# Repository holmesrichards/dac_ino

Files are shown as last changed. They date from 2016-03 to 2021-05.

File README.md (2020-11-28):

# dac/ino

This is a pair of boards and corresponding library which provide CV and gate I/O for an Arduino Nano. It is derived from [shaduzlabs/synapse](https://github.com/shaduzlabs/synapse), and there are obvious similarities to [ArdCore](http://20objects.com/ardcore/), but there are significant differences with both. 

There are two boards, dac/ino and dac/ino lite.

Differences between these and Synapse are:

- Board design with space for Arduino Nano, instead of as Uno style shield
- No on-board jacks — pads for Molex or pin connectors (or direct soldering) instead
- Simplification by eliminating software-controlled range selection
- Number of inputs and outputs is different
- dac/ino lite is battery powered and has 0–5 V output range, also uses Arduino Vcc as voltage reference

## Features
### dac/ino has
- 4 x control voltage inputs, 0 to 5V
- 2 x control voltage outputs, individually configurable as 0 to 5 V, 0 to 10 V, or -5 to 5 V via jumpers, with 12 bits of resolution
- 4 x gate inputs (with interrupt)
- 2 x gate outputs
- Additional inputs/outputs (direct connections to Arduino): 4 analog, 2 digital
- All above inputs/outputs connect via Molex connectors or solder pads, or via pin headers for daughterboards
- Voltage reference chip
- 1 x eurorack power connector (10 pin)

### dac/ino lite has
- 2 x control voltage outputs, 0 to 5 V, with 12 bits of resolution
- 1 x gate output
- Additional inputs/outputs (direct connections to Arduino): 4 analog, 2 digital
- All above inputs/outputs connect via Molex connectors or solder pads
- 6–12 V battery or unipolar power supply

## Compatible Arduinos
The PCB layout is for an Arduino Nano (5V).

## Dependencies
- [DirectIO](https://github.com/mmarchetti/DirectIO), for fast digital pin access

## Respository
- KiCad format schematics and PCB layouts, and Arduino library and example sketches, may be found at [https://github.com/holmesrichards/dac_ino](https://github.com/holmesrichards/dac_ino).

- [Build notes](docs/Build_notes.md)
- [dac/ino schematic](docs/dac_ino.pdf) (A bit confusing because the repetitive parts of the circuit are handled with KiCad heirarchical pages, so you have lots of pages with only a few components on each.)

- [dac/ino PCB layout](docs/dac_ino_pcb.pdf)

- [dac/ino BOM](docs/dac_ino_bom.md)

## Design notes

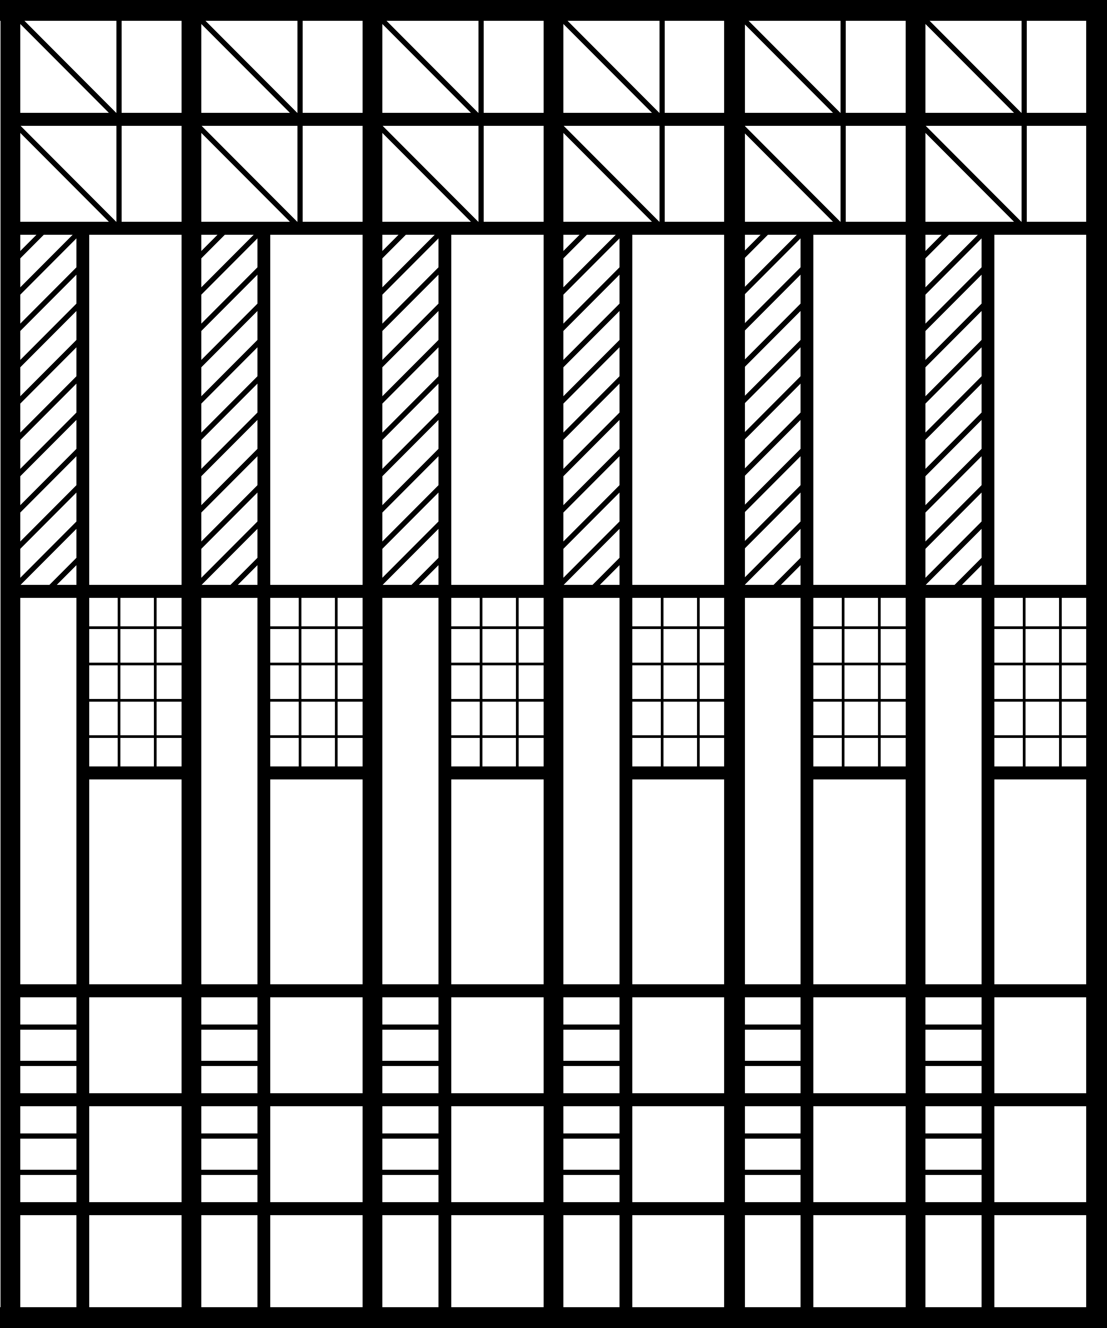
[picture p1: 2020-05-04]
hardware/dac_ino/deco2_dac_ino.png

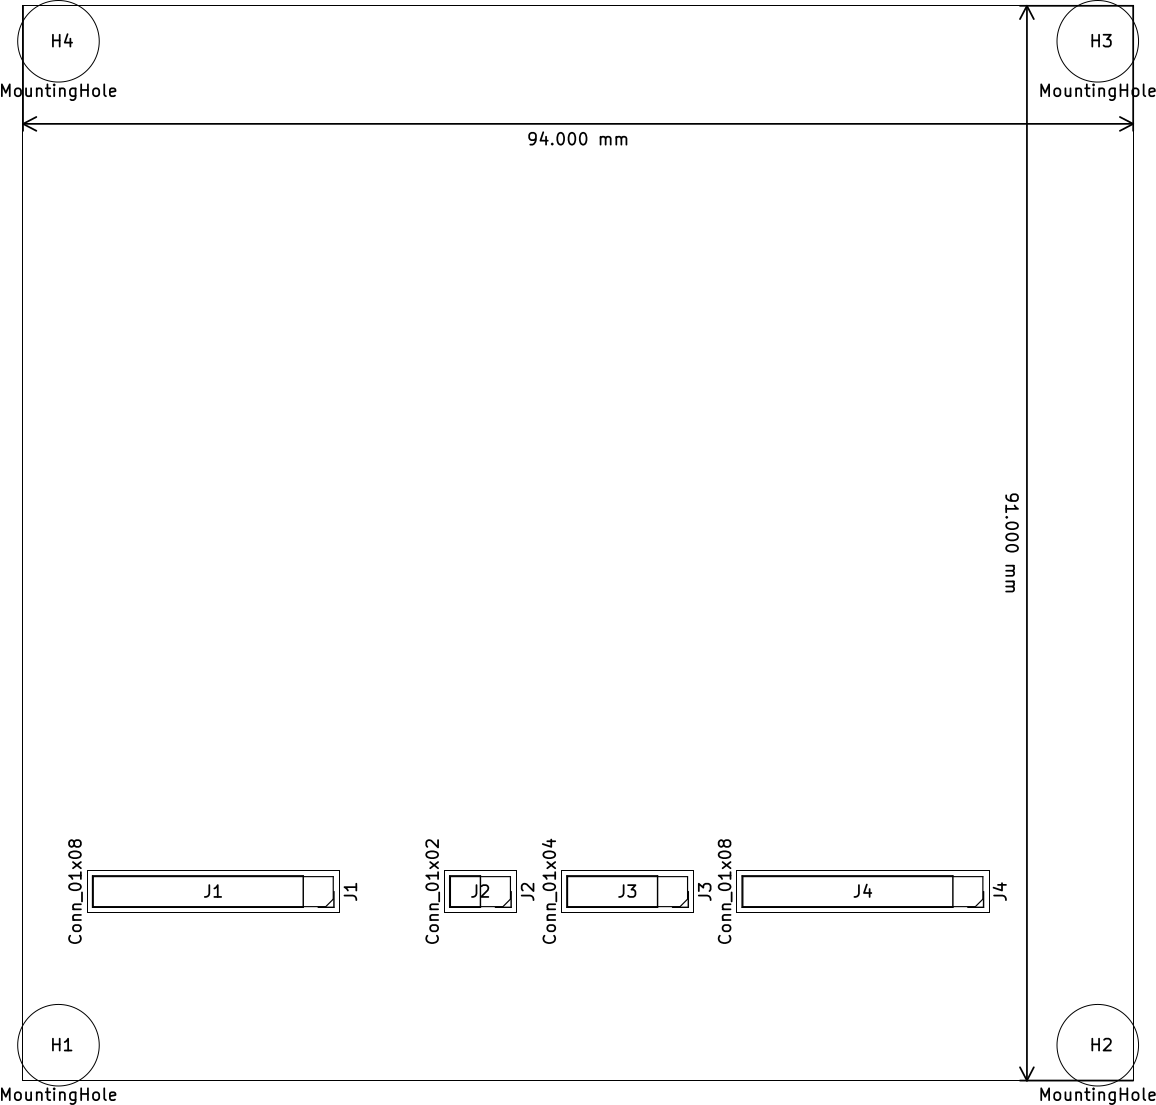
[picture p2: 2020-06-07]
hardware/daughterboard/daughterboard.png

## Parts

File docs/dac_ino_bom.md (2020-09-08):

# dac_ino BOM

Tue 08 Sep 2020 07:13:33 PM EDT

Generated from schematic by Eeschema 5.1.6-c6e7f7d~87~ubuntu20.04.1

**Component Count:** 83

| Value | Qty | Part | Description | Vendor |
| ----- | --- | ---- | --- | --- |
| A1 | 1 | Arduino_Nano_v3.x 5V | Arduino Nano v3.x |  |
| C1, C7, C8 | 3 | 10uF | Polarized capacitor |  |
| C2, C3, C4 | 3 | 0.1uF | Unpolarized capacitor |  |
| C5, C6 | 2 | 47pF | Unpolarized capacitor |  |
| D1, D2, D3, D4, D5, D6, D7, D8, D9, D10 | 10 | 1N5817 | 20V 1A Schottky Barrier Rectifier Diode, DO-41 |  |
| H1, H2, H3, H4 | 4 | MountingHole | Mounting Hole without connection |  |
| J1, J2 | 2 | Conn_01x03_Male | Generic connector, single row, 01x03, script generated (kicad-library-utils/schlib/autogen/connector/) |  |
| J3, J4 | 2 | Molex 2 pin CV OUT | Generic connector, single row, 01x02, script generated (kicad-library-utils/schlib/autogen/connector/) |  |
| J5, J6 | 2 | Molex 2 pin GATE OUT | Generic connector, single row, 01x02, script generated (kicad-library-utils/schlib/autogen/connector/) |  |
| J7, J14 | 2 | Conn_01x01_Units | Generic connector, single row, 01x01, script generated (kicad-library-utils/schlib/autogen/connector/) |  |
| J8 | 1 | Molex 2 pin VCC  | Generic connector, single row, 01x02, script generated (kicad-library-utils/schlib/autogen/connector/) |  |
| J9 | 1 | EURO_PWR_2x5 |  |  |
| J10 | 1 | Conn_01x04 | Generic connector, single row, 01x04, script generated (kicad-library-utils/schlib/autogen/connector/) |  |
| J11 | 1 | Conn_01x02 | Generic connector, single row, 01x02, script generated (kicad-library-utils/schlib/autogen/connector/) |  |
| J12, J13, J19, J20 | 4 | Molex 2 pin GATE IN | Generic connector, single row, 01x02, script generated (kicad-library-utils/schlib/autogen/connector/) |  |
| J15, J16, J17, J18 | 4 | Molex 2 pin CV IN | Generic connector, single row, 01x02, script generated (kicad-library-utils/schlib/autogen/connector/) |  |
| J21 | 1 | Conn_01x06 | Generic connector, single row, 01x08, script generated (kicad-library-utils/schlib/autogen/connector/) |  |
| Q1, Q2, Q3, Q4, Q5, Q6 | 6 | 2N3904 | 0.2A Ic, 40V Vce, Small Signal NPN Transistor, TO-92 |  |
| R1, R14, R17, R20, R27, R30 | 6 | 10k | Resistor |  |
| R2, R3 | 2 | 91k | Resistor |  |
| R4, R5 | 2 | 20k | Trim-potentiometer |  |
| R6, R7, R15, R18, R25, R28 | 6 | 100k | Resistor |  |
| R8, R9, R10, R11, R12, R13, R21, R22, R23, R24 | 10 | 1k | Resistor |  |
| R16, R19, R26, R29 | 4 | 1M | Resistor |  |
| U1 | 1 | MCP4922 | 2-Channel 12-Bit D/A Converters with SPI Interface |  |
| U2 | 1 | TL072 | Dual Low-Noise JFET-Input Operational Amplifiers, DIP-8/SOIC-8 |  |
| U3 | 1 | REF02CP+ | High Precision, 5V Reference, DIP-8, SO-8 |  |

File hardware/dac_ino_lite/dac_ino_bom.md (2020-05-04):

# dac_ino BOM

Mon 04 May 2020 10:25:07 AM EDT

Generated from schematic by Eeschema 5.1.5-52549c5~84~ubuntu18.04.1

**Component Count:** 23

| Value | Qty | Part | Description | Vendor |
| ----- | --- | ---- | --- | --- |
| A1 | 1 | Arduino_Nano_v3.x 5V | Arduino Nano v3.x |  |
| C1, C4 | 2 | 10uF | Polarized capacitor |  |
| C2 | 1 | 0.1uF | Unpolarized capacitor |  |
| H1, H2, H3, H4 | 4 | MountingHole | Mounting Hole without connection |  |
| J1 | 1 | CV OUT A | Generic connector, single row, 01x02, script generated (kicad-library-utils/schlib/autogen/connector/) |  |
| J2 | 1 | CV OUT B | Generic connector, single row, 01x02, script generated (kicad-library-utils/schlib/autogen/connector/) |  |
| J5 | 1 | GATE OUT A | Generic connector, single row, 01x02, script generated (kicad-library-utils/schlib/autogen/connector/) |  |
| J6, J7 | 2 | Conn_01x04 | Generic connector, single row, 01x04, script generated (kicad-library-utils/schlib/autogen/connector/) |  |
| J8 | 1 | VCC | Generic connector, single row, 01x02, script generated (kicad-library-utils/schlib/autogen/connector/) |  |
| J9 | 1 | Vin | Generic connector, single row, 01x02, script generated (kicad-library-utils/schlib/autogen/connector/) |  |
| Q1 | 1 | 2N3904 | 0.2A Ic, 40V Vce, Small Signal NPN Transistor, TO-92 |  |
| R1, R8 | 2 | 10k | Resistor |  |
| R2, R3, R6, R7 | 4 | 1k | Resistor |  |
| U1 | 1 | MCP4922 | 2-Channel 12-Bit D/A Converters with SPI Interface |  |

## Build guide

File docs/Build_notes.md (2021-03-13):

# dac/ino build notes

## General build notes
The main thing to say about building this board is that it is very modular. Most components are associated with one particular input or output and if that input/output is not needed, those components can be omitted.

For example (for the full dac/ino board, similar ideas apply to dac/ino lite):

If you do not need Gate In D you can omit J13, Q4, R18, R19, R20

If you do not need CV In D you can omit D9, D10, J18, R24

If you do not need Gate Out B you can omit J6, Q2, R12, R13

If you do not need CV Out B you can omit C6, J2, J4, R3, R5, R7, R9 (use a wire jumper in place of C6)

Note that R14 is placed near the CV inputs but is not associated with them and should always be installed.

## Full dac/ino

### Silkscreen error
In version 1.3, the silkscreened reference numbers and values for R28 and R29 are reversed. R29 (1M) should be between R28 (100k) and R30 (10k). Fixed in version 1.31. Corrected version looks like this:

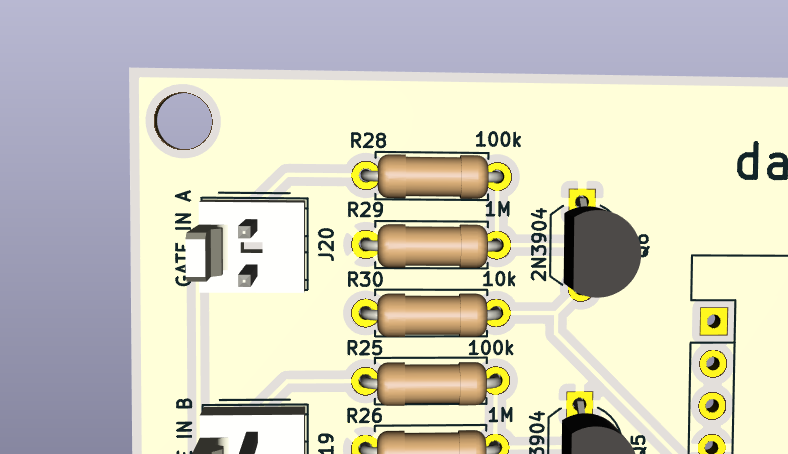
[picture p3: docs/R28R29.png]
R28 and R29 correct positions
 
### dac/ino build notes

The two 1x8 pin headers J7 and J14 duplicate the 2-pin Molex connectors; either or both can be installed and either can be used to connect to the Gate and CV inputs and outputs, and to access VCC and ground. 8-pin Molex connector J21, or in headers J10 and J11, provide access to two additional digital pins and four additional analog pins; these can be used for e.g. panel switches and pots where input protection and conditioning is not needed. Of course you can also omit any of the Molex connectors or pin headers and solder wires directly between the panel and board.

Pin headers J1 and J2 are for output CV range selection. Use a jumper to connect the middle pin to the pin toward the power header edge of the board to get 0–10 V, or the middle pin to the pin toward the CV In edge of the board to get ±5 V; omit the jumper to get 0–5 V. Use trimmers R4 and R5 to adjust the output gain.

Orient the Arduino Nano with the USB connector pointing toward the Analog Output logo.

## dac/ino lite

Provide power to this board by connecting a 6 to 12 V DC source to J9. The "+" on the silkscreen indicates which pin receives voltage, the other is ground.

There are no Gate or CV inputs provided; there are solder pads for direct connection to four digital and four analog pins.

R2 and R3 are output current limiting resistors.

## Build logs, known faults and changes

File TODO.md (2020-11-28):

# dac/ino ideas for future improvements

* ±5 V output relies on VCC for bias. Really should rely on voltage reference instead.

* Gate inputs are not protected against negative inputs. (Reverse voltage rating for 2N3904 is 6 V.) Add 1N4148 between base and ground.

* Limitation to 0–5 V inputs is unsatisfactory. A CV input that can optionally divide by 2 and optionally offset by 2.5 V would allow converting 0–10 V or ±5 V to the 0–5 V range. This would add several components including a quad op amp. Perhaps use e.g. MCP6004 powered with VCC and ground, obviating need for Schottkys for Arduino protection.

* Board is inconveniently wide already and we're talking about adding components! Consider: 
    * Converting design to 2-layer sandwich
    * Surface mount design
    * Switching to DAC with internal voltage reference (2.5 V or 5 V would be good but I see none in through hole package, just MCP4822 with 2.048 V)

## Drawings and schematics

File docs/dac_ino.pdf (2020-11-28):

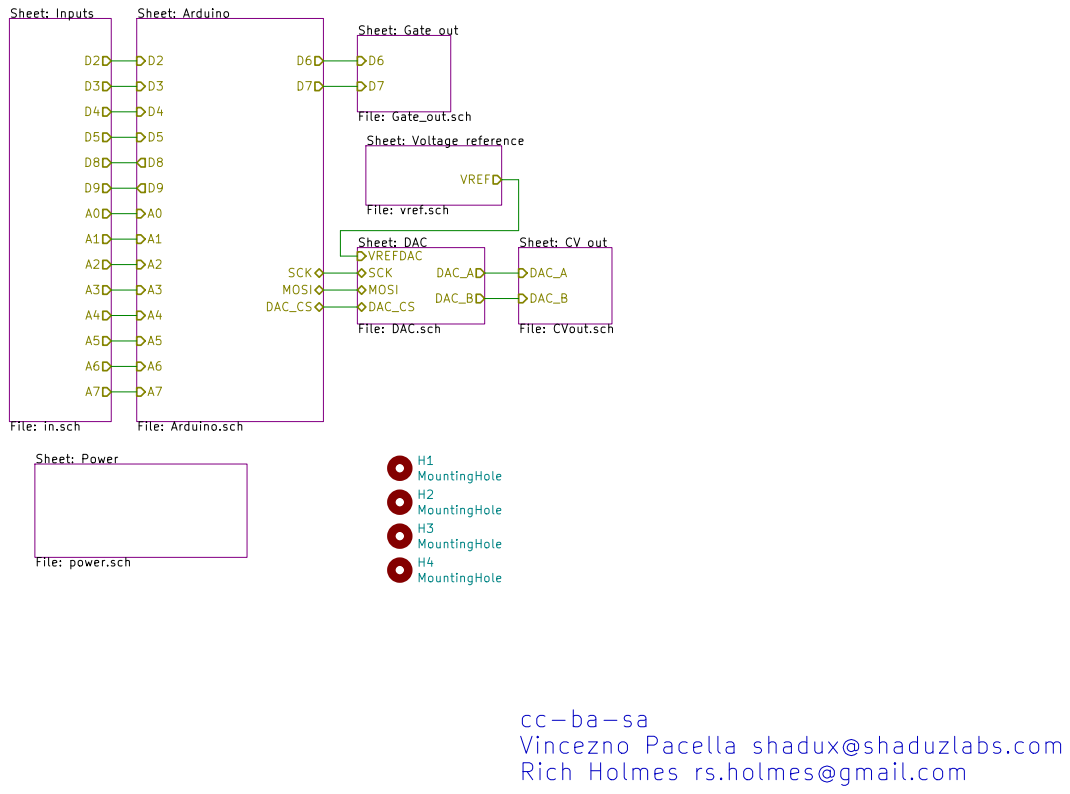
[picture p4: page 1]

Sheet: CV out File: CVout.sch DAC_A DAC_B

Vincezno Pacella shadux@shaduzlabs.com
Rich Holmes rs.holmes@gmail.com

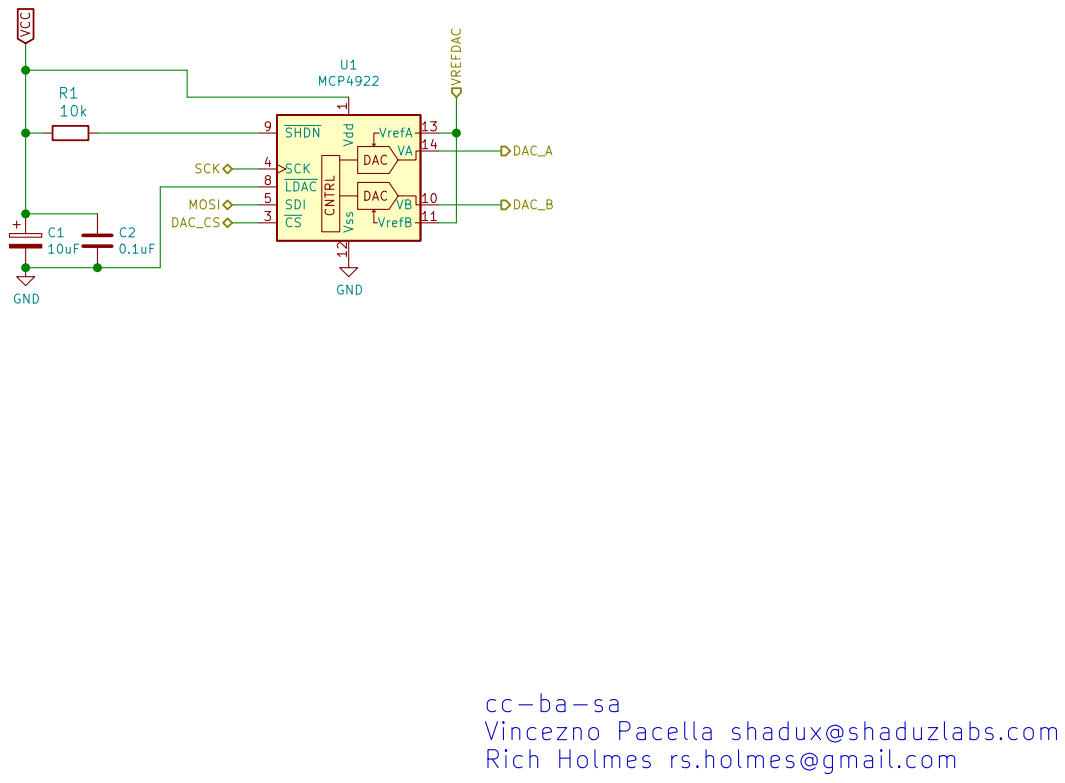
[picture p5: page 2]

1 VB 10 VrefB 11 Vss 12 VrefA 13 VA 14 CS 3 SCK 4 SDI 5

Vincezno Pacella shadux@shaduzlabs.com
Rich Holmes rs.holmes@gmail.com

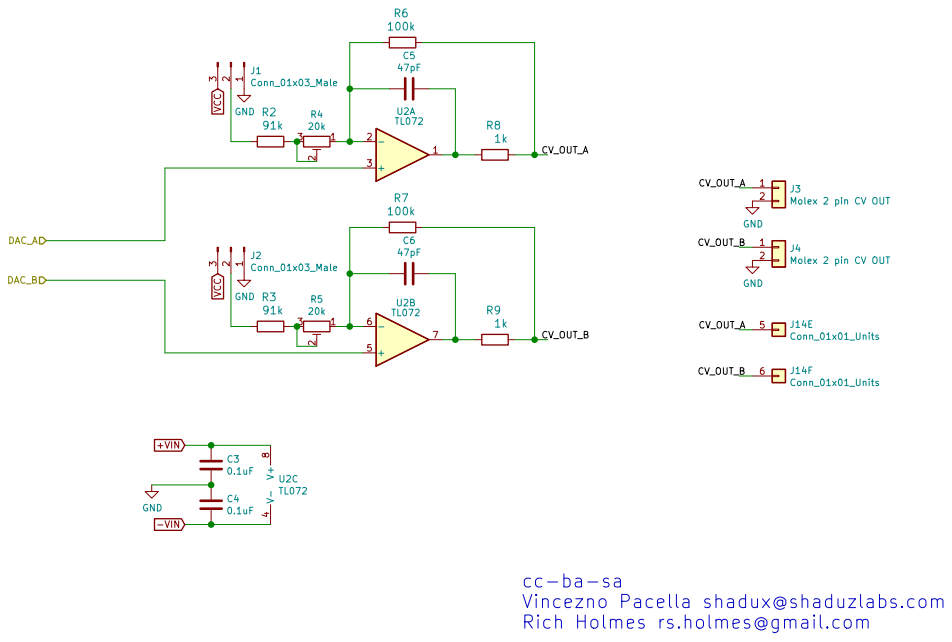
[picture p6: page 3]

Vincezno Pacella shadux@shaduzlabs.com
Rich Holmes rs.holmes@gmail.com

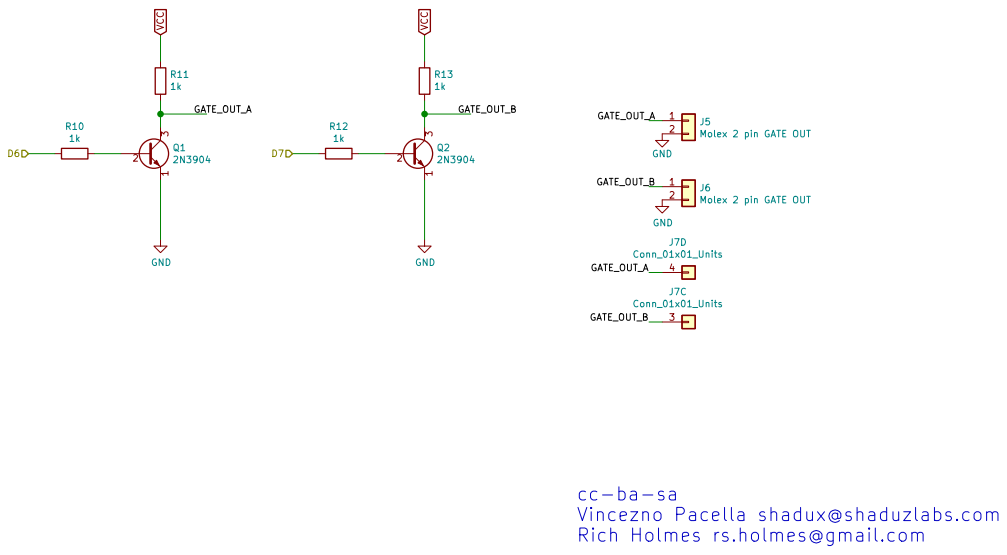
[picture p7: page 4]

Vincezno Pacella shadux@shaduzlabs.com
Rich Holmes rs.holmes@gmail.com

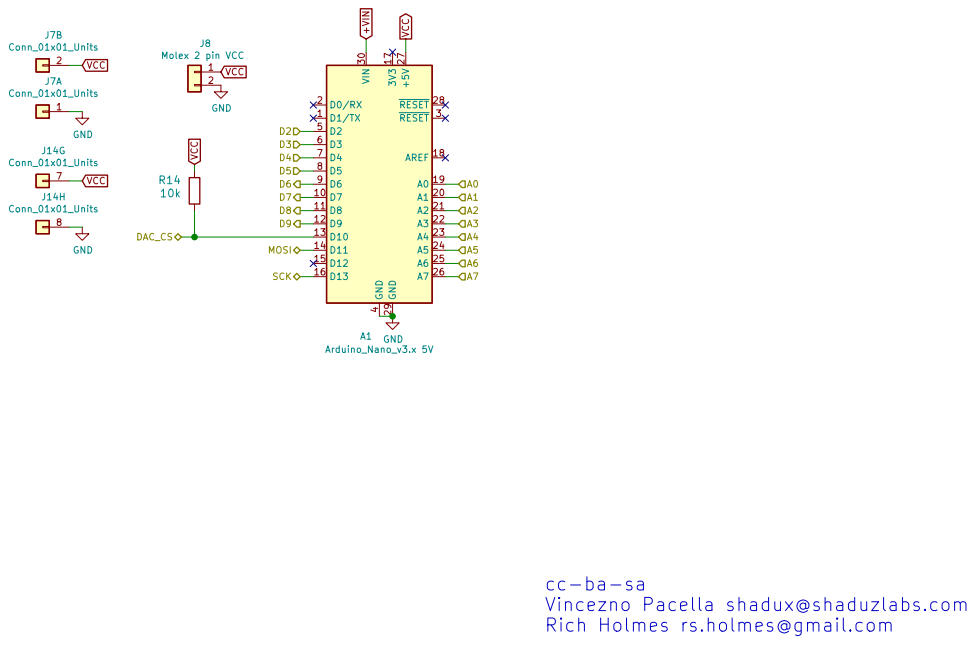
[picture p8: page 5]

J8 Molex 2 pin VCC GND

Vincezno Pacella shadux@shaduzlabs.com
Rich Holmes rs.holmes@gmail.com

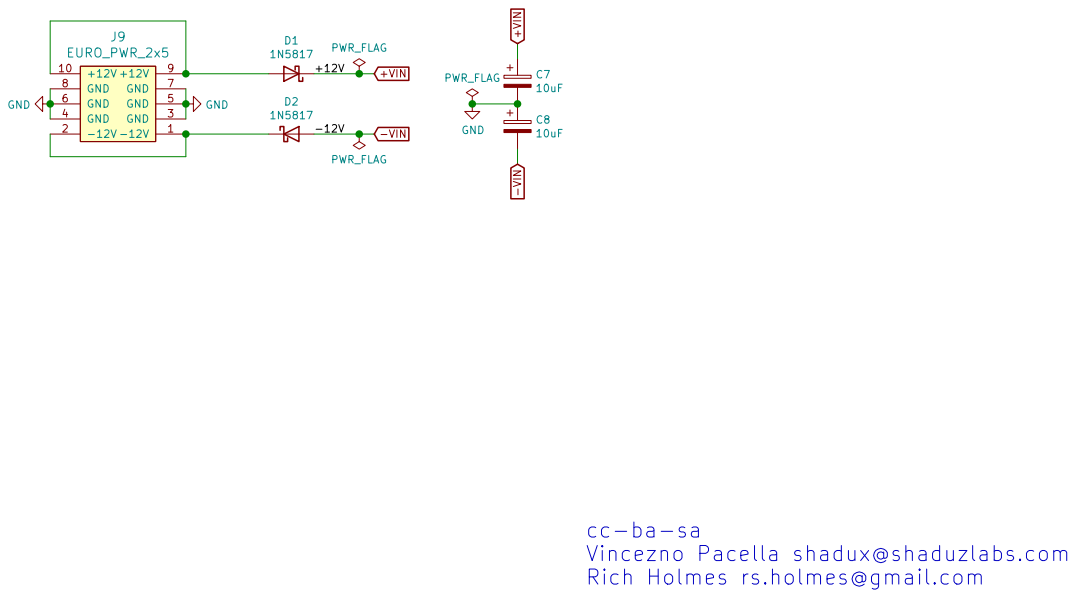
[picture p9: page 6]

Vincezno Pacella shadux@shaduzlabs.com
Rich Holmes rs.holmes@gmail.com

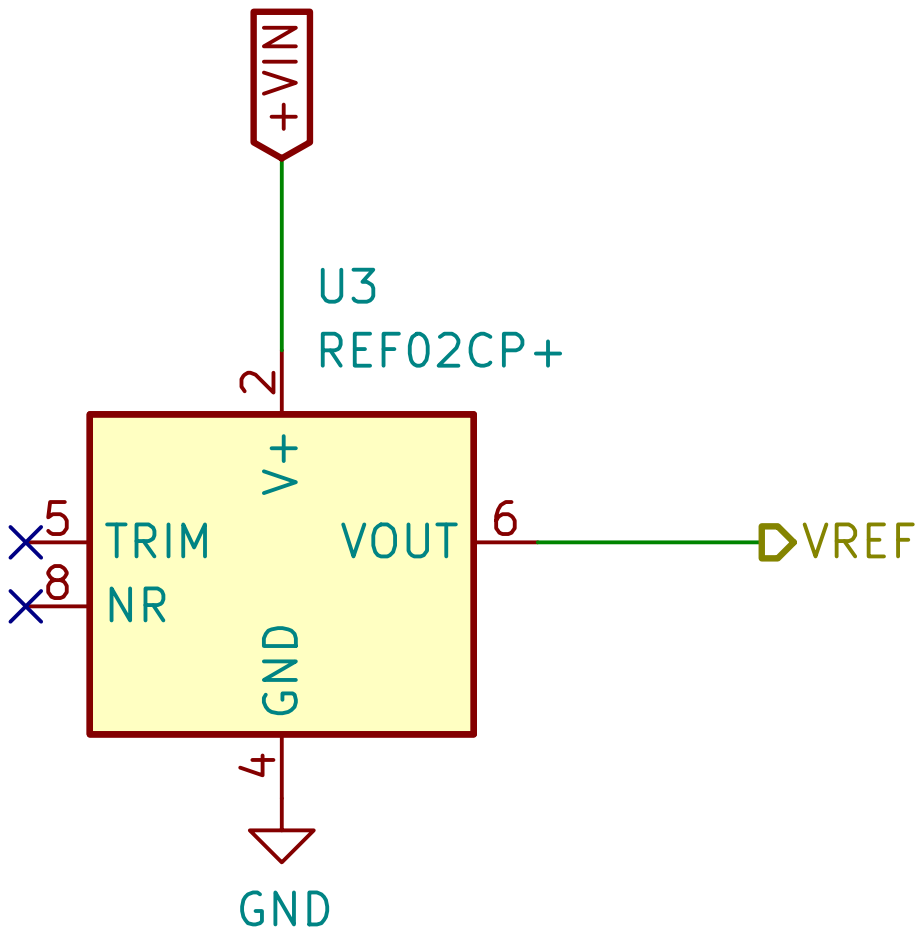
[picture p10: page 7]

4 TRIM 5 VOUT 6 NR 8 U3REF02CP+ GND

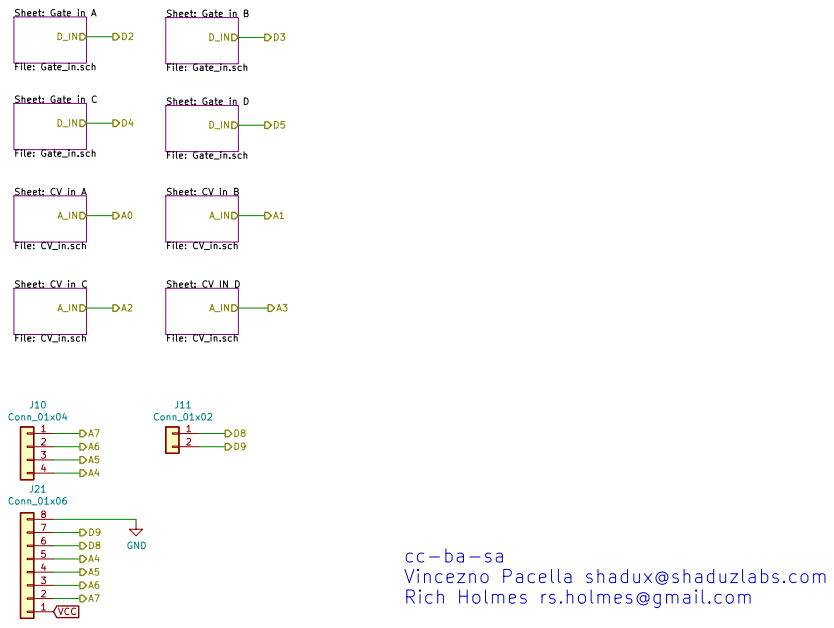
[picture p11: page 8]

Vincezno Pacella shadux@shaduzlabs.com
Rich Holmes rs.holmes@gmail.com

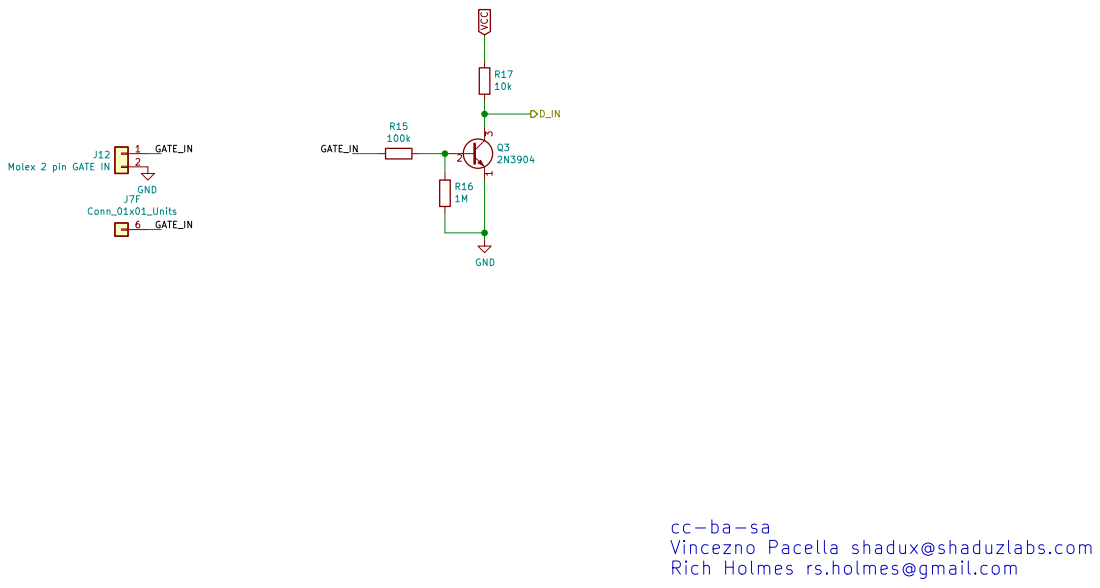
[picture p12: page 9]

J12 Molex 2 pin GATE IN

Vincezno Pacella shadux@shaduzlabs.com
Rich Holmes rs.holmes@gmail.com

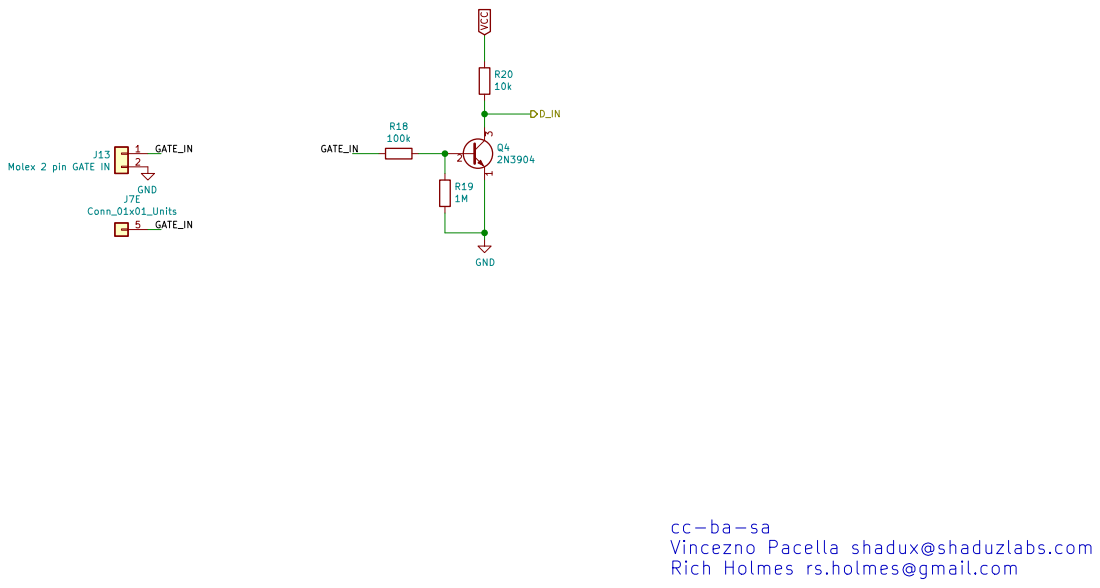
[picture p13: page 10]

J13 Molex 2 pin GATE IN

Vincezno Pacella shadux@shaduzlabs.com
Rich Holmes rs.holmes@gmail.com

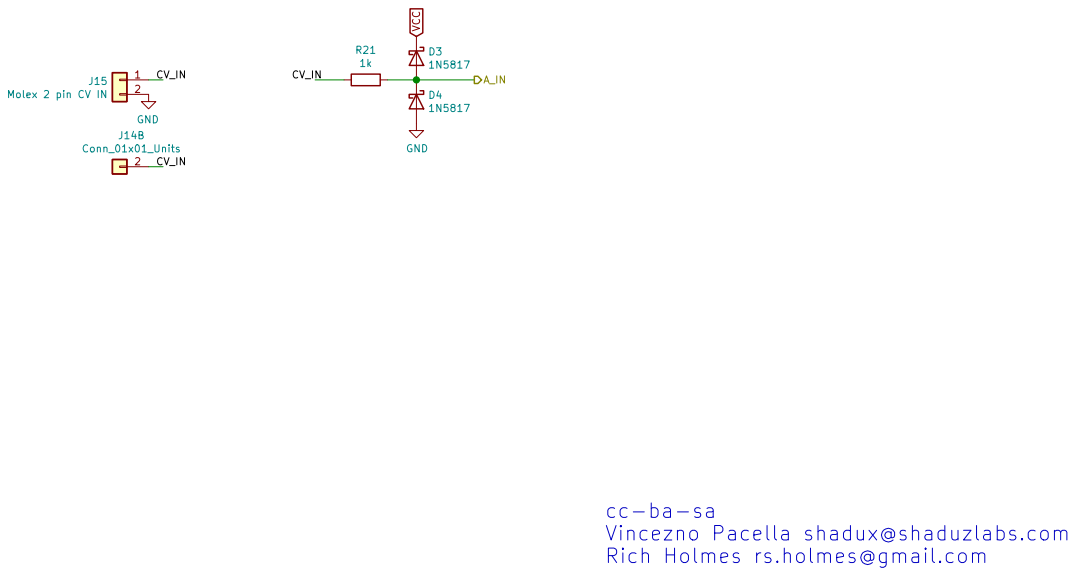
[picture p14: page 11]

J15 Molex 2 pin CV IN

Vincezno Pacella shadux@shaduzlabs.com
Rich Holmes rs.holmes@gmail.com

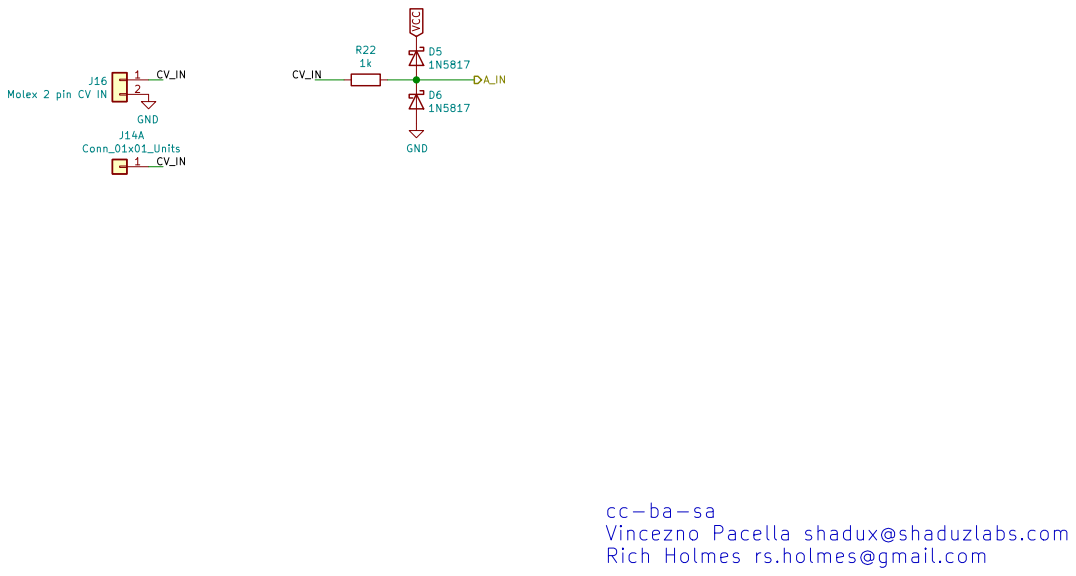
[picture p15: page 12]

J16 Molex 2 pin CV IN

Vincezno Pacella shadux@shaduzlabs.com
Rich Holmes rs.holmes@gmail.com


J17 Molex 2 pin CV IN

Vincezno Pacella shadux@shaduzlabs.com
Rich Holmes rs.holmes@gmail.com


J18 Molex 2 pin CV IN

Vincezno Pacella shadux@shaduzlabs.com
Rich Holmes rs.holmes@gmail.com


J19 Molex 2 pin GATE IN

Vincezno Pacella shadux@shaduzlabs.com
Rich Holmes rs.holmes@gmail.com


J20 Molex 2 pin GATE IN

Vincezno Pacella shadux@shaduzlabs.com
Rich Holmes rs.holmes@gmail.com





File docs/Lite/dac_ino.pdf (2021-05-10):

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

based on Synapse by Vincenzo Pacella shadux@shaduzlabs.com
File: dac_ino.sch Sheet: / Rich Holmes / Analog Output

Id: 1/1 Title: dac/ino lite

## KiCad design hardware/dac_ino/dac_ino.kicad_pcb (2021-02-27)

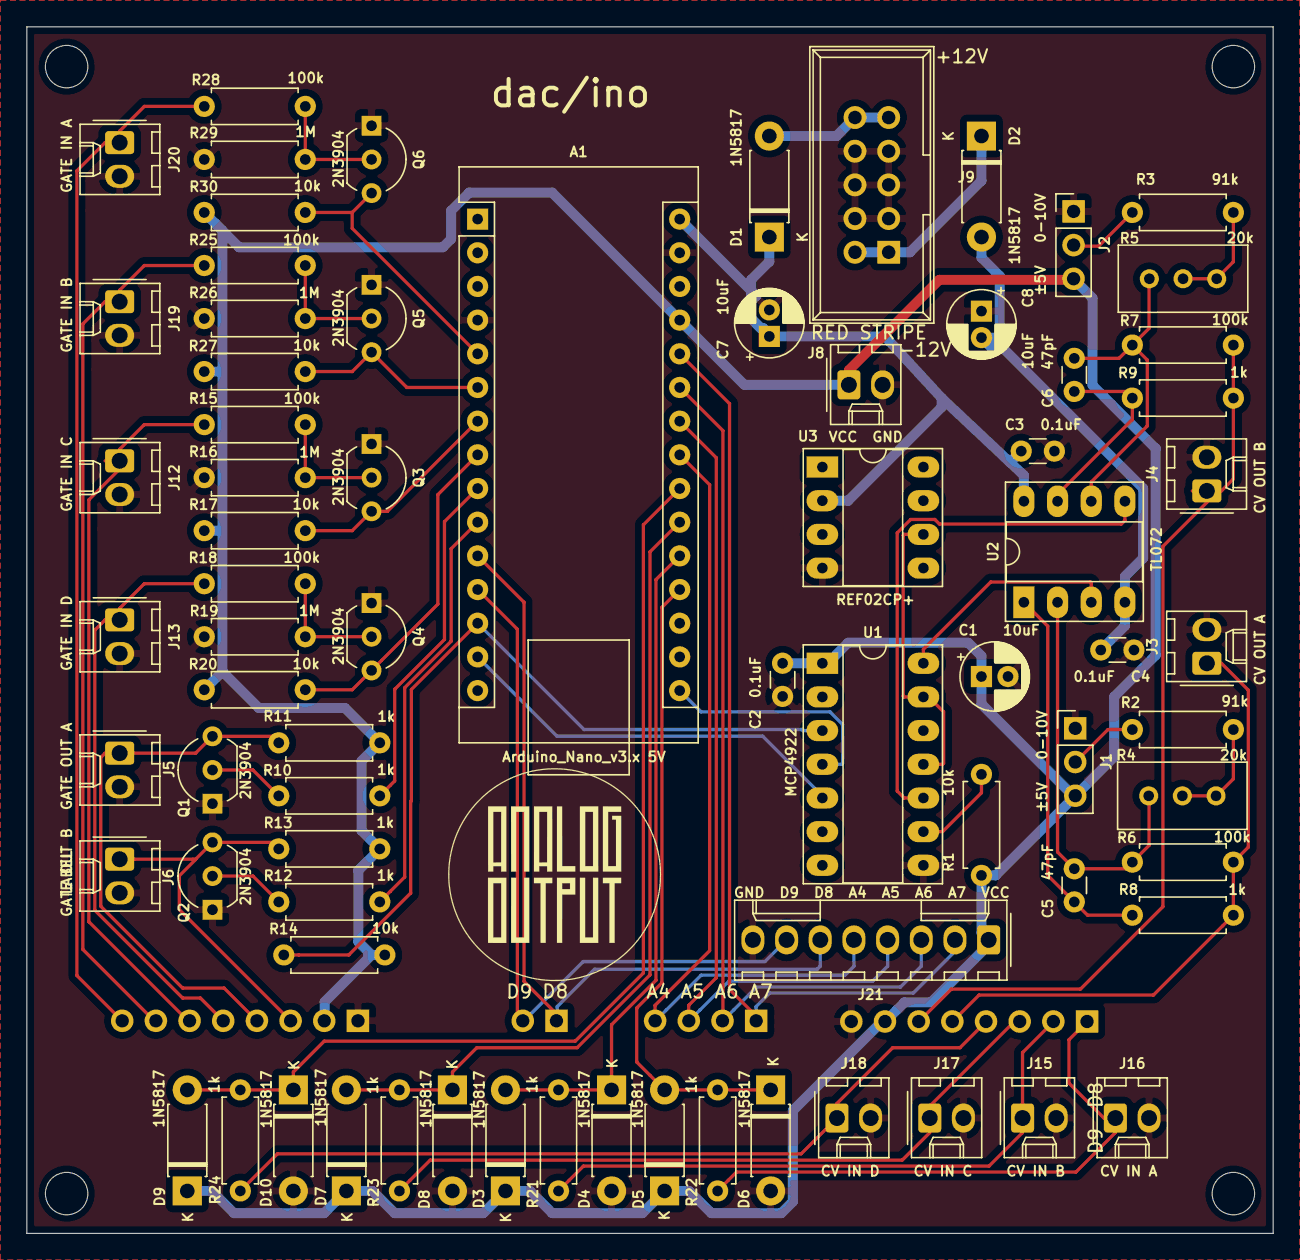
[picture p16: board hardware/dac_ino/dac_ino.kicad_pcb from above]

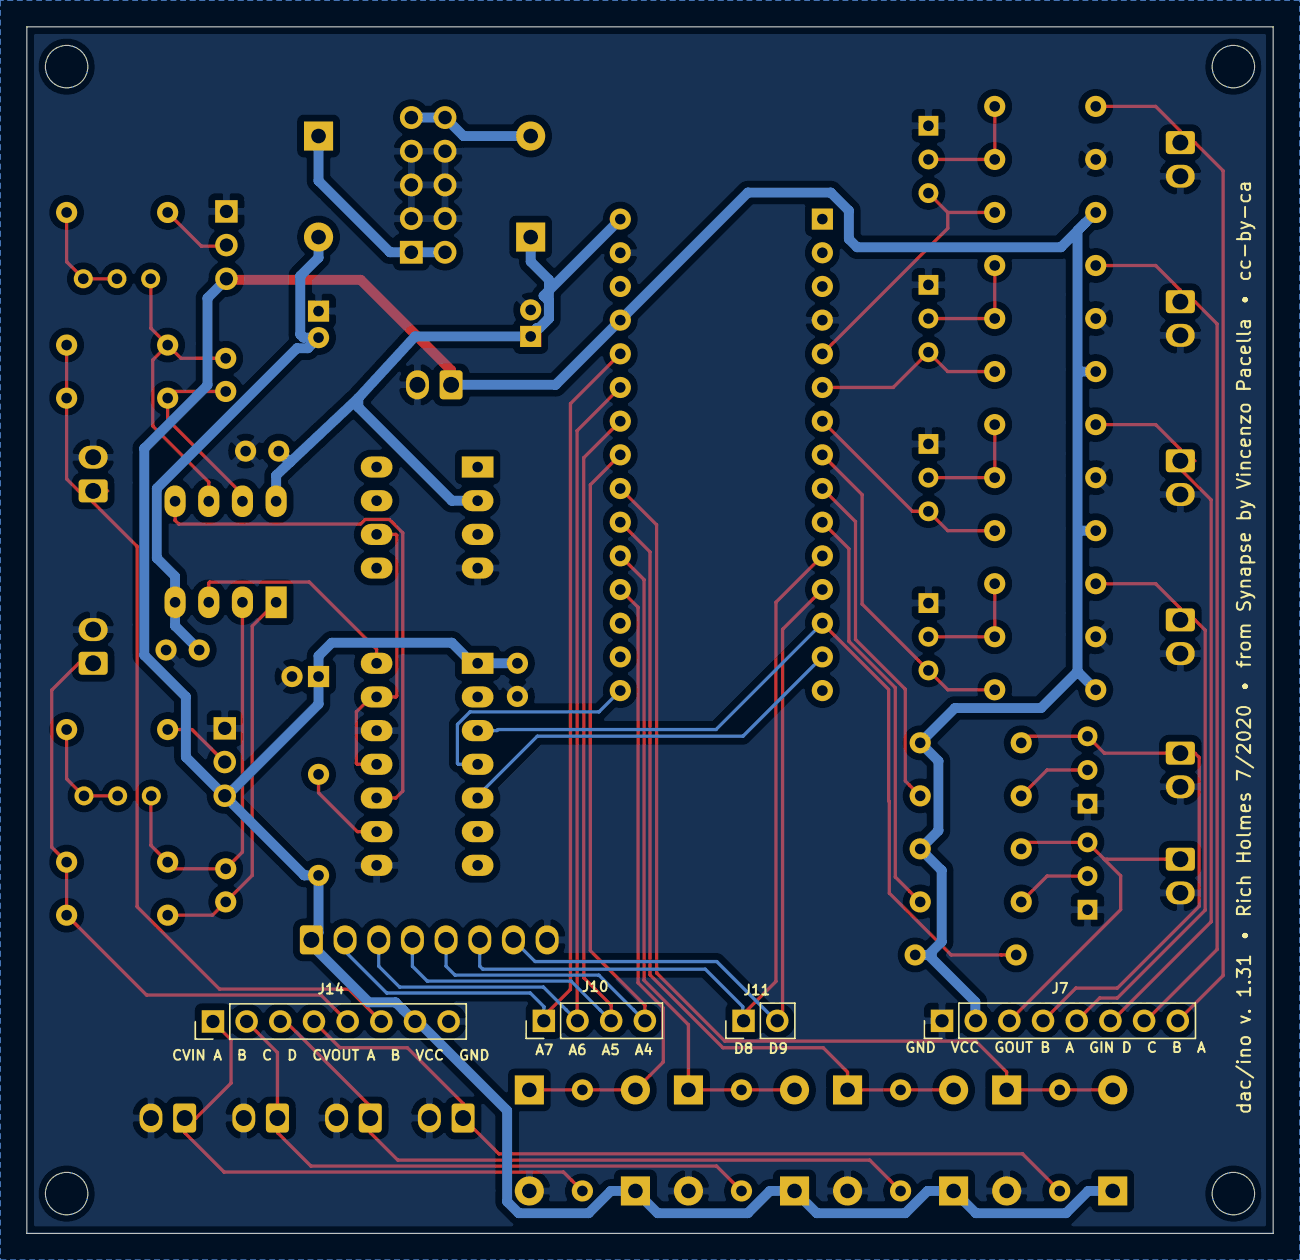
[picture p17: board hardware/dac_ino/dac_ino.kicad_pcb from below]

Board: 2 copper layers, 94.0 x 91.0 mm, 83 parts (4 on the bottom side), 55 nets.

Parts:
A1: Arduino_Nano_v3.x 5V; Arduino_Nano
C1, C7, C8: 10uF; CP_Radial_D5.0mm_P2.00mm
C2, C3, C4: 0.1uF; C_Disc_D3.0mm_W1.6mm_P2.50mm
C5, C6: 47pF; C_Disc_D3.0mm_W1.6mm_P2.50mm
D1, D2, D3, D4, D5, D6, D7, D8, D9, D10: 1N5817; D_DO-41_SOD81_P7.62mm_Horizontal
H1, H2, H3, H4: MountingHole; MountingHole_3.2mm_M3
J1, J2: Conn_01x03_Male; PinHeader_1x03_P2.54mm_Vertical
J3, J4: Molex 2 pin CV OUT; Molex_KK-254_AE-6410-02A_1x02_P2.54mm_Vertical
J5, J6: Molex 2 pin GATE OUT; Molex_KK-254_AE-6410-02A_1x02_P2.54mm_Vertical
J7, J14: Conn_01x01_Units; PinHeader_1x08_P2.54mm_Vertical
J8: Molex 2 pin VCC; Molex_KK-254_AE-6410-02A_1x02_P2.54mm_Vertical
J9: EURO_PWR_2x5; Power_Header
J10: Conn_01x04; PinHeader_1x04_P2.54mm_Vertical
J11: Conn_01x02; PinHeader_1x02_P2.54mm_Vertical
J12, J13, J19, J20: Molex 2 pin GATE IN; Molex_KK-254_AE-6410-02A_1x02_P2.54mm_Vertical
J15, J16, J17, J18: Molex 2 pin CV IN; Molex_KK-254_AE-6410-02A_1x02_P2.54mm_Vertical
J21: Conn_01x06; Molex_KK-254_AE-6410-08A_1x08_P2.54mm_Vertical
Q1, Q2, Q3, Q4, Q5, Q6: 2N3904; TO-92_Inline_Wide
R1, R14, R17, R20, R27, R30: 10k; R_Axial_DIN0207_L6.3mm_D2.5mm_P7.62mm_Horizontal
R2, R3: 91k; R_Axial_DIN0207_L6.3mm_D2.5mm_P7.62mm_Horizontal
R4, R5: 20k; Potentiometer_Bourns_3296W_Vertical
R6, R7, R15, R18, R25, R28: 100k; R_Axial_DIN0207_L6.3mm_D2.5mm_P7.62mm_Horizontal
R8, R9, R10, R11, R12, R13, R21, R22, R23, R24: 1k; R_Axial_DIN0207_L6.3mm_D2.5mm_P7.62mm_Horizontal
R16, R19, R26, R29: 1M; R_Axial_DIN0207_L6.3mm_D2.5mm_P7.62mm_Horizontal
U1: MCP4922; DIP-14_W7.62mm_Socket_LongPads
U2: TL072; DIP-8_W7.62mm_Socket_LongPads
U3: REF02CP+; DIP-8_W7.62mm_Socket_LongPads

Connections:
+VIN: A1.30, C3.1, C7.1, D1.1, U2.8, U3.2
-VIN: C4.2, C8.2, D2.2, U2.4
/Arduino/A0: A1.19, D5.2, D6.1, R22.1
/Arduino/A1: A1.20, D3.2, D4.1, R21.1
/Arduino/A2: A1.21, D7.2, D8.1, R23.1
/Arduino/A3: A1.22, D9.2, D10.1, R24.1
/Arduino/A4: A1.23, J10.4, J21.5
/Arduino/A5: A1.24, J10.3, J21.4
/Arduino/A6: A1.25, J10.2, J21.3
/Arduino/A7: A1.26, J10.1, J21.2
/Arduino/D2: A1.5, Q6.3, R30.1
/Arduino/D3: A1.6, Q5.3, R27.1
/Arduino/D4: A1.7, Q3.3, R17.1
/Arduino/D5: A1.8, Q4.3, R20.1
/Arduino/D6: A1.9, R10.2
/Arduino/D7: A1.10, R12.2
/Arduino/D8: A1.11, J11.1, J21.6
/Arduino/D9: A1.12, J11.2, J21.7
/Arduino/DAC_CS: A1.13, R14.2, U1.3
/Arduino/MOSI: A1.14, U1.5
/Arduino/SCK: A1.16, U1.4
/CV out/CV_OUT_A: J3.1, J14.5, R6.2, R8.2
/CV out/CV_OUT_B: J4.1, J14.6, R7.2, R9.2
/CV out/DAC_A: U1.14, U2.3
/CV out/DAC_B: U1.10, U2.5
/Gate out/GATE_OUT_A: J5.1, J7.4, Q1.3, R11.1
/Gate out/GATE_OUT_B: J6.1, J7.3, Q2.3, R13.1
/Inputs/CV IN D/CV_IN: J14.4, J18.1, R24.2
/Inputs/CV in A/CV_IN: J14.1, J16.1, R22.2
/Inputs/CV in B/CV_IN: J14.2, J15.1, R21.2
/Inputs/CV in C/CV_IN: J14.3, J17.1, R23.2
/Inputs/Gate in A/GATE_IN: J7.8, J20.1, R28.2
/Inputs/Gate in B/GATE_IN: J7.7, J19.1, R25.2
/Inputs/Gate in C/GATE_IN: J7.6, J12.1, R15.2
/Inputs/Gate in D/GATE_IN: J7.5, J13.1, R18.2
/Voltage reference/VREF: U1.11, U1.13, U3.6
GND: A1.4, A1.29, C1.2, C2.2, C3.2, C4.1, C7.2, C8.1, D4.2, D6.2, D8.2, D10.2, J1.1, J2.1, J3.2, J4.2, J5.2, J6.2, J7.1, J8.2, J9.3, J9.4, J9.5, J9.6, J9.7, J9.8, J12.2, J13.2, J14.8, J15.2, J16.2, J17.2, J18.2, J19.2, J20.2, J21.8, Q1.1, Q2.1, Q3.1, Q4.1, Q5.1, Q6.1, R16.1, R19.1, R26.1, R29.1, U1.8, U1.12, U3.4
unnamed: C5.1, R8.1, U2.1
unnamed: C5.2, R4.1, R6.1, U2.2
unnamed: C6.1, R9.1, U2.7
unnamed: C6.2, R5.1, R7.1, U2.6
unnamed: D1.2, J9.9, J9.10
unnamed: D2.1, J9.1, J9.2
unnamed: J1.2, R2.1
unnamed: J2.2, R3.1
unnamed: Q1.2, R10.1
unnamed: Q2.2, R12.1
unnamed: Q3.2, R15.1, R16.2
unnamed: Q4.2, R18.1, R19.2
unnamed: Q5.2, R25.1, R26.2
unnamed: Q6.2, R28.1, R29.2
unnamed: R1.2, U1.9
unnamed: R2.2, R4.2, R4.3
unnamed: R3.2, R5.2, R5.3
VCC: A1.27, C1.1, C2.1, D3.1, D5.1, D7.1, D9.1, J1.3, J2.3, J7.2, J8.1, J14.7, J21.1, R1.1, R11.2, R13.2, R14.1, R17.2, R20.2, R27.2, R30.2, U1.1

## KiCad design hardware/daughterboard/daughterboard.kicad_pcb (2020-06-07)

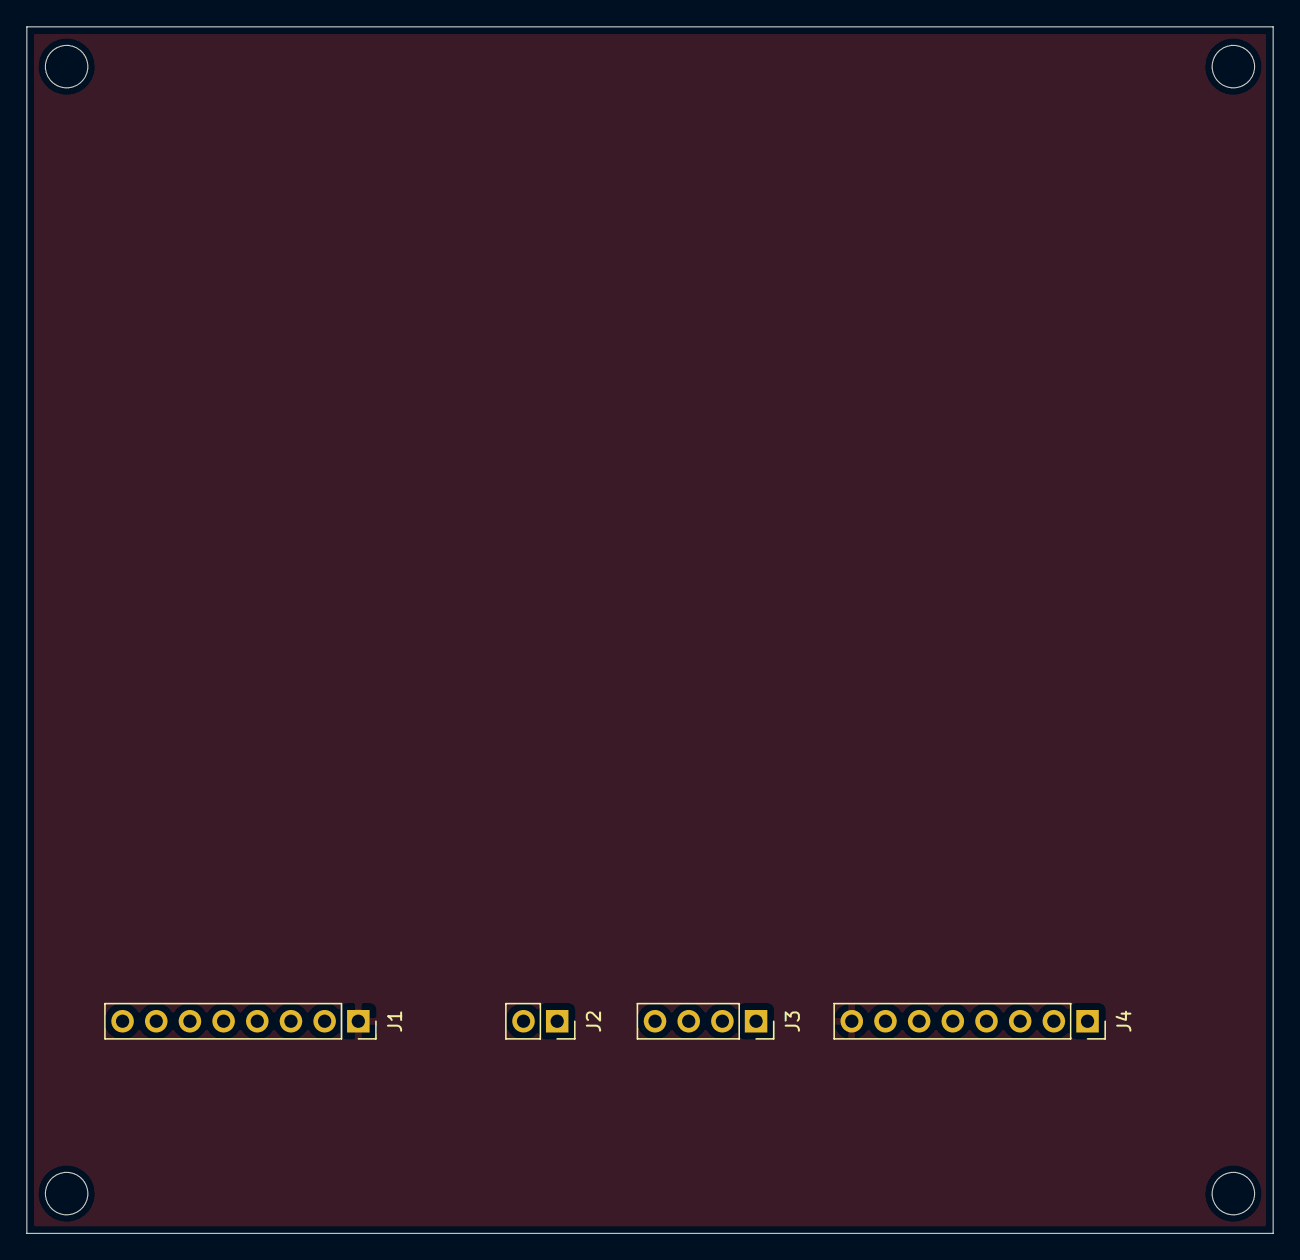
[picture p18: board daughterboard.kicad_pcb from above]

Board: 2 copper layers, 94.0 x 91.0 mm, 8 parts (0 on the bottom side), 2 nets, no tracks yet.

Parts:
H1, H2, H3, H4: MountingHole; MountingHole_3.2mm_M3
J1, J4: Conn_01x08; PinSocket_1x08_P2.54mm_Vertical
J2: Conn_01x02; PinSocket_1x02_P2.54mm_Vertical
J3: Conn_01x04; PinSocket_1x04_P2.54mm_Vertical

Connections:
GND: J1.1, J4.8
VCC: J1.2, J4.7

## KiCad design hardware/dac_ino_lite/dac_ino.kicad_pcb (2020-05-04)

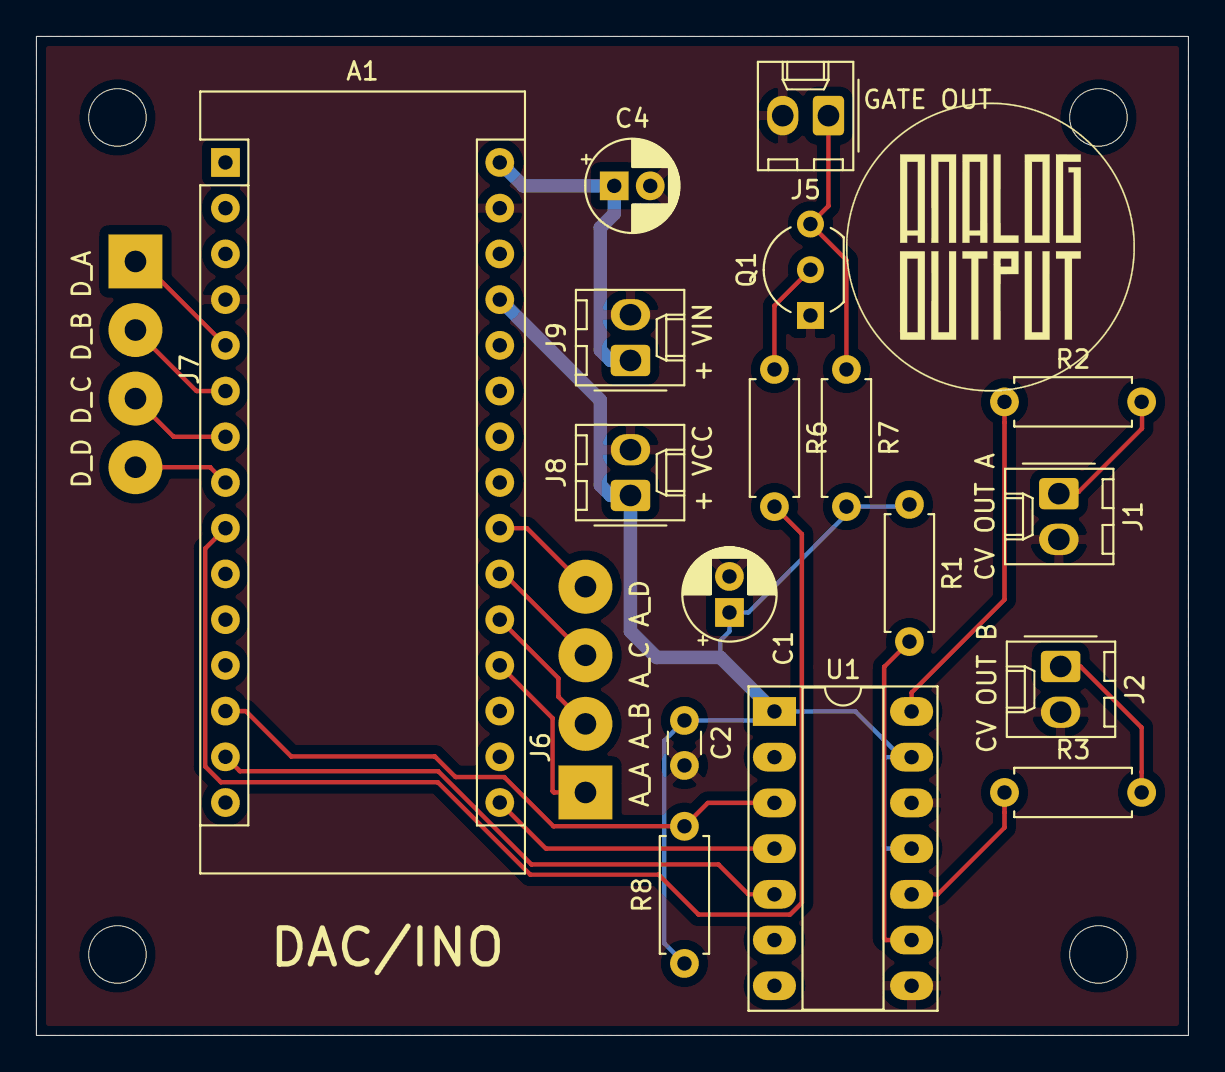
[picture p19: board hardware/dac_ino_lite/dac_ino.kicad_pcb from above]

Board: 2 copper layers, 64.0 x 55.5 mm, 23 parts (0 on the bottom side), 22 nets.

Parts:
A1: Arduino_Nano_v3.x 5V; Arduino_Nano
C1, C4: 10uF; CP_Radial_D5.0mm_P2.00mm
C2: 0.1uF; C_Disc_D3.0mm_W1.6mm_P2.50mm
H1, H2, H3, H4: MountingHole; MountingHole_3.2mm_M3
J1: CV OUT A; Molex_KK-254_AE-6410-02A_1x02_P2.54mm_Vertical
J2: CV OUT B; Molex_KK-254_AE-6410-02A_1x02_P2.54mm_Vertical
J5: GATE OUT A; Molex_KK-254_AE-6410-02A_1x02_P2.54mm_Vertical
J6, J7: Conn_01x04; SolderWirePad_1x04_P3.81mm_Drill1.2mm
J8: VCC; Molex_KK-254_AE-6410-02A_1x02_P2.54mm_Vertical
J9: Vin; Molex_KK-254_AE-6410-02A_1x02_P2.54mm_Vertical
Q1: 2N3904; TO-92_Inline_Wide
R1, R8: 10K; R_Axial_DIN0207_L6.3mm_D2.5mm_P7.62mm_Horizontal
R2, R3: 1K; R_Axial_DIN0207_L6.3mm_D2.5mm_P7.62mm_Horizontal
R6, R7: 1k; R_Axial_DIN0207_L6.3mm_D2.5mm_P7.62mm_Horizontal
U1: MCP4922; DIP-14_W7.62mm_Socket_LongPads

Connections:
+VIN: A1.30, C4.1, J9.1
/Arduino/A_IN_A: A1.19, J6.1
/Arduino/A_IN_B: A1.20, J6.2
/Arduino/A_IN_C: A1.21, J6.3
/Arduino/A_IN_D: A1.22, J6.4
/Arduino/DAC_CS: A1.13, R8.2, U1.3
/Arduino/D_IN_A: A1.5, J7.1
/Arduino/D_IN_B: A1.6, J7.2
/Arduino/D_IN_C: A1.7, J7.3
/Arduino/D_IN_D: A1.8, J7.4
/Arduino/D_OUT_A: A1.9, R6.2
/Arduino/MOSI: A1.14, U1.5
/Arduino/SCK: A1.16, U1.4
/DAC/CV_OUT_A: J1.1, R2.2
/DAC/CV_OUT_B: J2.1, R3.2
/Gate out/GATE_OUT: J5.1, Q1.3, R7.1
GND: A1.4, A1.29, C1.2, C2.2, C4.2, J1.2, J2.2, J5.2, J8.2, J9.2, Q1.1, U1.8, U1.12
unnamed: Q1.2, R6.1
unnamed: R1.2, U1.9
unnamed: R2.1, U1.14
unnamed: R3.1, U1.10
VCC: A1.27, C1.1, C2.1, J8.1, R1.1, R7.2, R8.1, U1.1, U1.11, U1.13

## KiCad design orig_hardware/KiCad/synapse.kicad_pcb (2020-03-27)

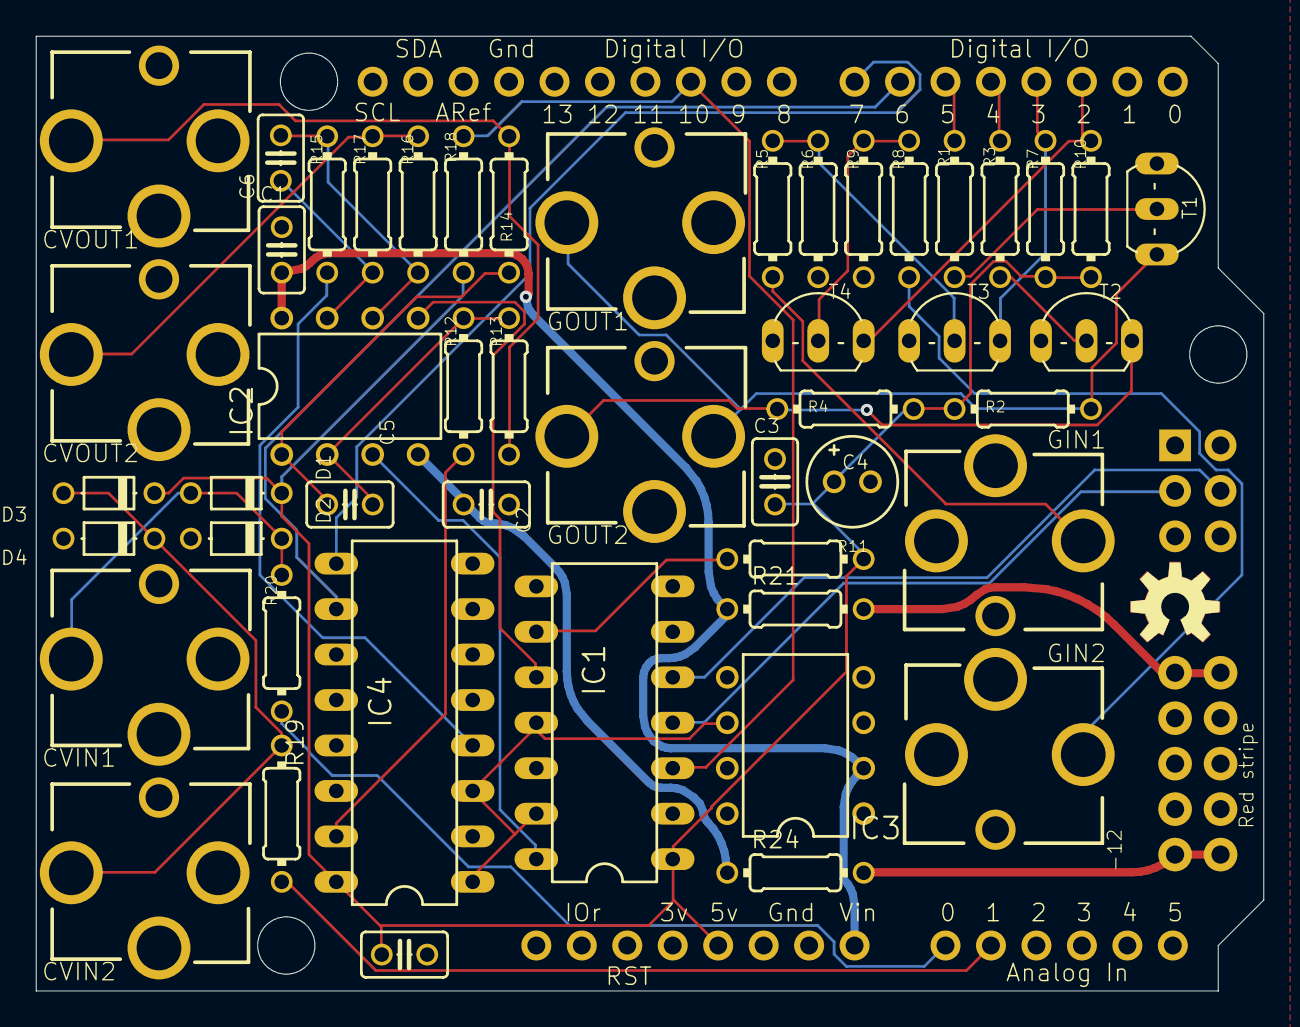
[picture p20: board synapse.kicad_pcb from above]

Board: 2 copper layers, 68.6 x 53.3 mm, 56 parts (0 on the bottom side), 39 nets.

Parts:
@HOLE0, @HOLE1, @HOLE2: (no value)
C1, C2, C3, C7: 100n; C025-025X050
C4: 10u; E2-5
C5, C6: 47p; C025-025X050
CVIN1, CVIN2: AUDIO-JACKERTHENVAR; ERTHENVAR-JACK
CVOUT1, CVOUT2: AUDIO-JACKERTHENVAR; ERTHENVAR-JACK
D1, D2, D3, D4: BAT85; D-5
GIN1, GIN2: AUDIO-JACKERTHENVAR; ERTHENVAR-JACK
GOUT1, GOUT2: AUDIO-JACKERTHENVAR; ERTHENVAR-JACK
IC1: MCP4922E_P; DIL14
IC2: TL072P; DIL08
IC3: REF02CP; DIL08
IC4: 4053N; DIL16
M1: ARDUINO_R3_ICSP; ARDUINOR3_ICSP
R1, R2, R3, R4, R14, R17, R19, R20: 1K; 0204_7
R5, R8, R12, R13, R15, R16: 100K; 0204_7
R6, R9: 1M; 0204_7
R7, R10, R11, R18: 10K; 0204_7
R21, R24: BEAD; 0204_7
T1, T2, T3, T4: 2N3904; TO92-EBC
U$1: OSHWLOGO_TOP_0.2
U$2: POWER_SIMPLE10; POWER_10
U$3: OSHW-LOGO-M

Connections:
/synapse_1/12V: C1.1, IC2.8, IC3.2, M1.VIN, R21.1
/synapse_1/-12V: C2.1, IC2.4, R24.1
/synapse_1/DAC_A: IC1.14, IC2.3
/synapse_1/DAC_B: IC1.10, IC2.5
/synapse_1/DAC_CS: IC1.3, M1.D10, R18.1
/synapse_1/MOSI: IC1.5, M1.MOSI
/synapse_1/SCK: IC1.4, M1.SCK
/synapse_2/GATE_IN_A: GIN1.3, R5.1
/synapse_2/GATE_IN_B: GIN2.3, R8.1
/synapse_2/GATE_OUT_A: GOUT1.3, GOUT2.2, R2.1, T1.C
/synapse_2/GATE_OUT_B: GOUT2.3, R4.1, T2.C
CFG_A: IC4.10, M1.D6
CFG_B: IC4.9, M1.D7
CV_IN_A: CVIN1.3, D1.A, D2.C, R20.1
CV_IN_B: CVIN2.3, D3.A, D4.C, R19.1
CV_OUT_A: CVOUT1.3, R13.1, R14.1
CV_OUT_B: CVOUT2.3, R16.1, R17.1
D_IN_A: M1.D3, R7.1, T3.C
D_IN_B: M1.D2, R10.1, T4.C
D_OUT_A: M1.D5, R1.1
D_OUT_B: M1.D4, R3.1
GND: C1.2, C2.2, C3.2, C4.-, C7.2, CVIN1.1@1, CVIN1.1@2, CVIN1.2, CVIN2.1@1, CVIN2.1@2, CVIN2.2, CVOUT1.1@1, CVOUT1.1@2, CVOUT2.1@1, CVOUT2.1@2, D2.A, D4.A, GIN1.1@1, GIN1.1@2, GIN1.2, GIN2.1@1, GIN2.1@2, GIN2.2, GOUT1.1@1, GOUT1.1@2, GOUT2.1@1, GOUT2.1@2, IC1.8, IC1.12, IC3.4, IC4.2, IC4.5, IC4.6, IC4.7, IC4.8, IC4.11, IC4.12, IC4.13, M1.GND, M1.GND@1, M1.GND@3, R6.1, R9.1, T1.E, T2.E, T3.E, T4.E, U$2.3, U$2.4, U$2.5, U$2.6, U$2.7, U$2.8
unnamed: C5.1, IC2.2, R12.1, R13.2
unnamed: C5.2, IC2.1, R14.2
unnamed: C6.1, IC2.6, R15.1, R16.2
unnamed: C6.2, IC2.7, R17.2
unnamed: IC1.9, R11.2
unnamed: M1.A0, R20.2
unnamed: M1.A1, R19.2
unnamed: R1.2, T1.B
unnamed: R3.2, T2.B
unnamed: R5.2, R6.2, T3.B
unnamed: R8.2, R9.2, T4.B
unnamed: R21.2, U$2.9, U$2.10
unnamed: R24.2, U$2.1, U$2.2
OFFSET_A: IC4.15, R12.2
OFFSET_B: IC4.4, R15.2
VCC: C3.1, C4.+, C7.1, D1.C, D3.C, IC1.1, IC4.16, M1.5V, R2.2, R4.2, R7.2, R10.2, R11.1, R18.2
VREF: IC1.11, IC1.13, IC3.6, IC4.1, IC4.3

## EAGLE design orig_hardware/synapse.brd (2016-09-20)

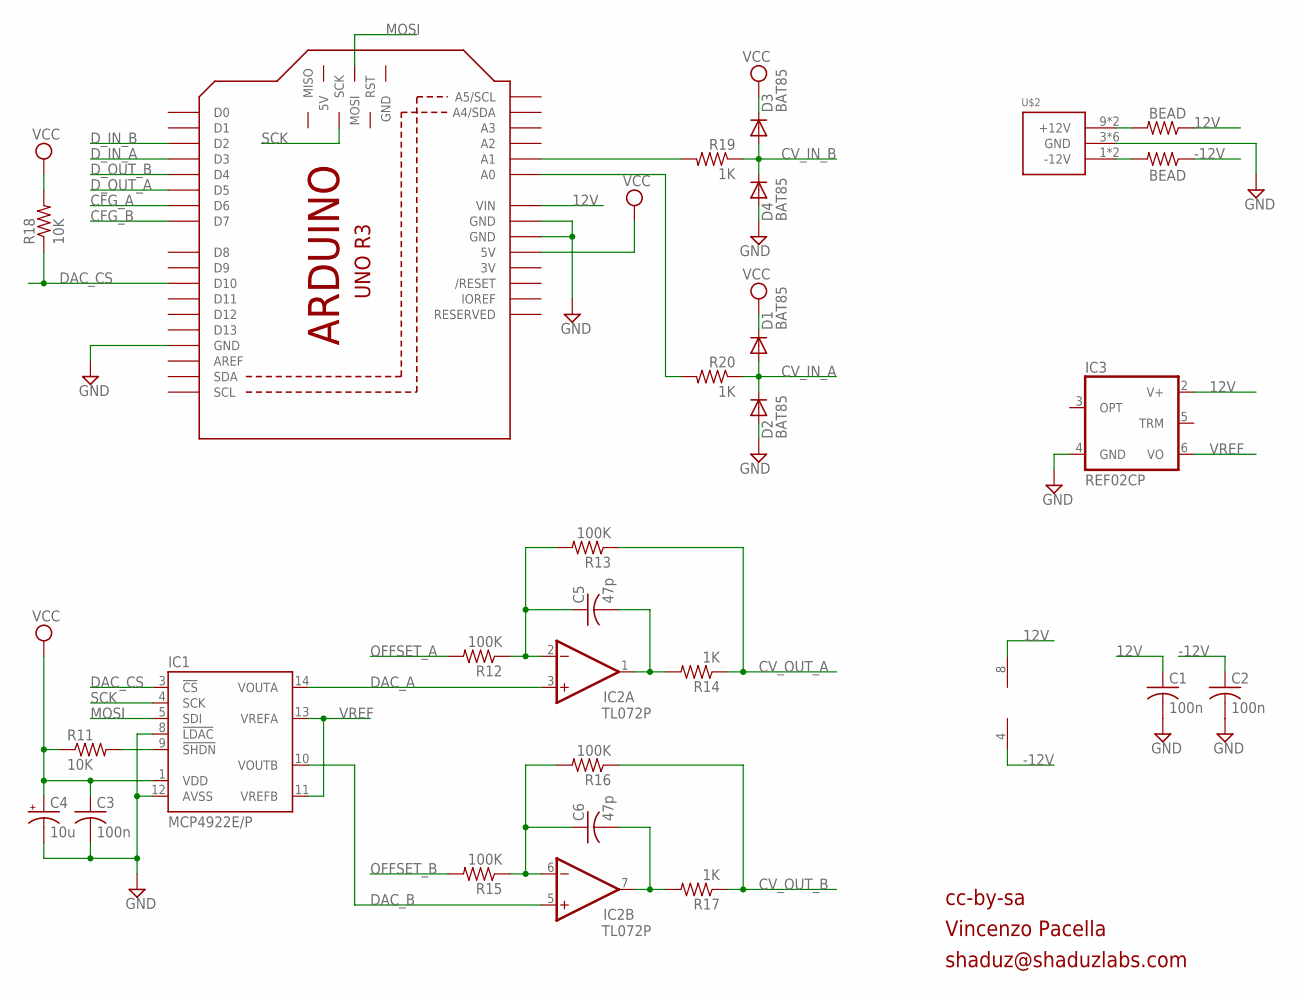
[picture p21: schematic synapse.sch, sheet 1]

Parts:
C1, C2, C3: 100n; C025-025X050
C4: 10u; E2-5
C5, C6: 47p; C025-025X050
D1, D2, D3, D4: BAT85; D-5
IC1: MCP4922E/P; DIL14
IC2: TL072P; DIL08
IC3: REF02CP; DIL08
M1: ARDUINO_R3_ICSP; ARDUINOR3_ICSP
R11, R18: 10K; 0204/7
R12, R13, R15, R16: 100K; 0204/7
R14, R17, R19, R20: 1K; 0204/7
R21, R24: BEAD; 0204/7
U$2: POWER_SIMPLE10; POWER_10

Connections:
3V: M1.3V
12V: C1.1, IC2.8 (V+), IC3.2 (V+), M1.VIN, R21.1
-12V: C2.1, IC2.4 (V-), R24.1
CFG_A: M1.D6; also elsewhere on the board
CFG_B: M1.D7; also elsewhere on the board
CV_IN_A: D1.A, D2.C, R20.1; also elsewhere on the board
CV_IN_B: D3.A, D4.C, R19.1; also elsewhere on the board
CV_OUT_A: R13.1, R14.1; also elsewhere on the board
CV_OUT_B: R16.1, R17.1; also elsewhere on the board
DAC_A: IC1.14 (VOUTA), IC2.3 (+IN)
DAC_B: IC1.10 (VOUTB), IC2.5 (+IN)
DAC_CS: IC1.3 (!CS!), M1.D10, R18.1
D_IN_A: M1.D3; also elsewhere on the board
D_IN_B: M1.D2; also elsewhere on the board
D_OUT_A: M1.D5; also elsewhere on the board
D_OUT_B: M1.D4; also elsewhere on the board
GND: C1.2, C2.2, C3.2, C4.-, D2.A, D4.A, IC1.8 (!LDAC!), IC1.12 (AVSS), IC3.4 (GND), M1.GND, M1.GND@1 (GND), M1.GND@3 (GND), U$2.3 (GND), U$2.4 (GND), U$2.5 (GND), U$2.6 (GND), U$2.7 (GND), U$2.8 (GND); also elsewhere on the board
MOSI: IC1.5 (SDI), M1.MOSI
unnamed: M1.A1, R19.2
unnamed: IC1.9 (!SHDN!), R11.2
unnamed: R21.2, U$2.9 (+12V), U$2.10 (+12V)
unnamed: R24.2, U$2.1 (-12V), U$2.2 (-12V)
unnamed: M1.A0, R20.2
unnamed: C5.1, IC2.2 (-IN), R12.1, R13.2
unnamed: C6.1, IC2.6 (-IN), R15.1, R16.2
unnamed: C5.2, IC2.1 (OUT), R14.2
unnamed: C6.2, IC2.7 (OUT), R17.2
OFFSET_A: R12.2; also elsewhere on the board
OFFSET_B: R15.2; also elsewhere on the board
SCK: IC1.4 (SCK), M1.SCK
VCC: C3.1, C4.+, D1.C, D3.C, IC1.1 (VDD), M1.5V, R11.1, R18.2; also elsewhere on the board
VREF: IC1.11 (VREFB), IC1.13 (VREFA), IC3.6 (VO); also elsewhere on the board

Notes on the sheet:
cc-by-sa
Vincenzo Pacella
shaduz@shaduzlabs.com

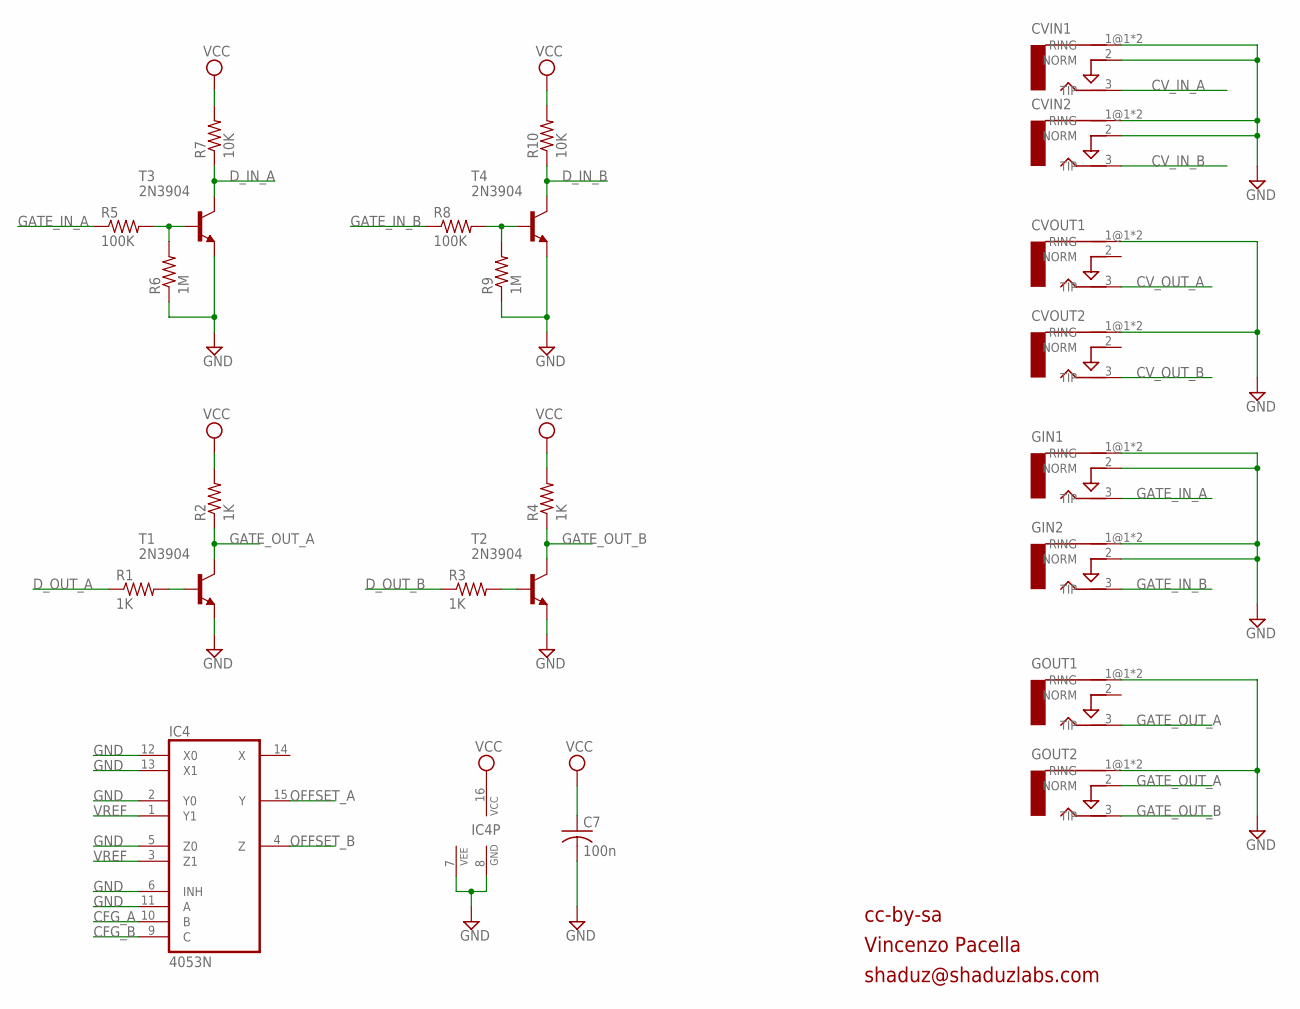
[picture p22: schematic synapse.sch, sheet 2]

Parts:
C7: 100n; C025-025X050
CVIN1, CVIN2: AUDIO-JACKERTHENVAR; ERTHENVAR-JACK
CVOUT1, CVOUT2: AUDIO-JACKERTHENVAR; ERTHENVAR-JACK
GIN1, GIN2: AUDIO-JACKERTHENVAR; ERTHENVAR-JACK
GOUT1, GOUT2: AUDIO-JACKERTHENVAR; ERTHENVAR-JACK
IC4: 4053N; DIL16
R1, R2, R3, R4: 1K; 0204/7
R5, R8: 100K; 0204/7
R6, R9: 1M; 0204/7
R7, R10: 10K; 0204/7
T1, T2, T3, T4: 2N3904; TO92-EBC

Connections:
CFG_A: IC4.10 (B); also elsewhere on the board
CFG_B: IC4.9 (C); also elsewhere on the board
CV_IN_A: CVIN1.3 (TIP); also elsewhere on the board
CV_IN_B: CVIN2.3 (TIP); also elsewhere on the board
CV_OUT_A: CVOUT1.3 (TIP); also elsewhere on the board
CV_OUT_B: CVOUT2.3 (TIP); also elsewhere on the board
D_IN_A: R7.1, T3.C; also elsewhere on the board
D_IN_B: R10.1, T4.C; also elsewhere on the board
D_OUT_A: R1.1; also elsewhere on the board
D_OUT_B: R3.1; also elsewhere on the board
GATE_IN_A: GIN1.3 (TIP), R5.1
GATE_IN_B: GIN2.3 (TIP), R8.1
GATE_OUT_A: GOUT1.3 (TIP), GOUT2.2 (NORM), R2.1, T1.C
GATE_OUT_B: GOUT2.3 (TIP), R4.1, T2.C
GND: C7.2, CVIN1.1@1 (RING), CVIN1.1@2 (RING), CVIN1.2 (NORM), CVIN2.1@1 (RING), CVIN2.1@2 (RING), CVIN2.2 (NORM), CVOUT1.1@1 (RING), CVOUT1.1@2 (RING), CVOUT2.1@1 (RING), CVOUT2.1@2 (RING), GIN1.1@1 (RING), GIN1.1@2 (RING), GIN1.2 (NORM), GIN2.1@1 (RING), GIN2.1@2 (RING), GIN2.2 (NORM), GOUT1.1@1 (RING), GOUT1.1@2 (RING), GOUT2.1@1 (RING), GOUT2.1@2 (RING), IC4.2 (Y0), IC4.5 (Z0), IC4.6 (INH), IC4.7 (VEE), IC4.8 (GND), IC4.11 (A), IC4.12 (X0), IC4.13 (X1), R6.1, R9.1, T1.E, T2.E, T3.E, T4.E; also elsewhere on the board
unnamed: R1.2, T1.B
unnamed: R3.2, T2.B
unnamed: R5.2, R6.2, T3.B
unnamed: R8.2, R9.2, T4.B
OFFSET_A: IC4.15 (Y); also elsewhere on the board
OFFSET_B: IC4.4 (Z); also elsewhere on the board
VCC: C7.1, IC4.16 (VCC), R2.2, R4.2, R7.2, R10.2; also elsewhere on the board
VREF: IC4.1 (Y1), IC4.3 (Z1); also elsewhere on the board

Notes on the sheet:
cc-by-sa
Vincenzo Pacella
shaduz@shaduzlabs.com

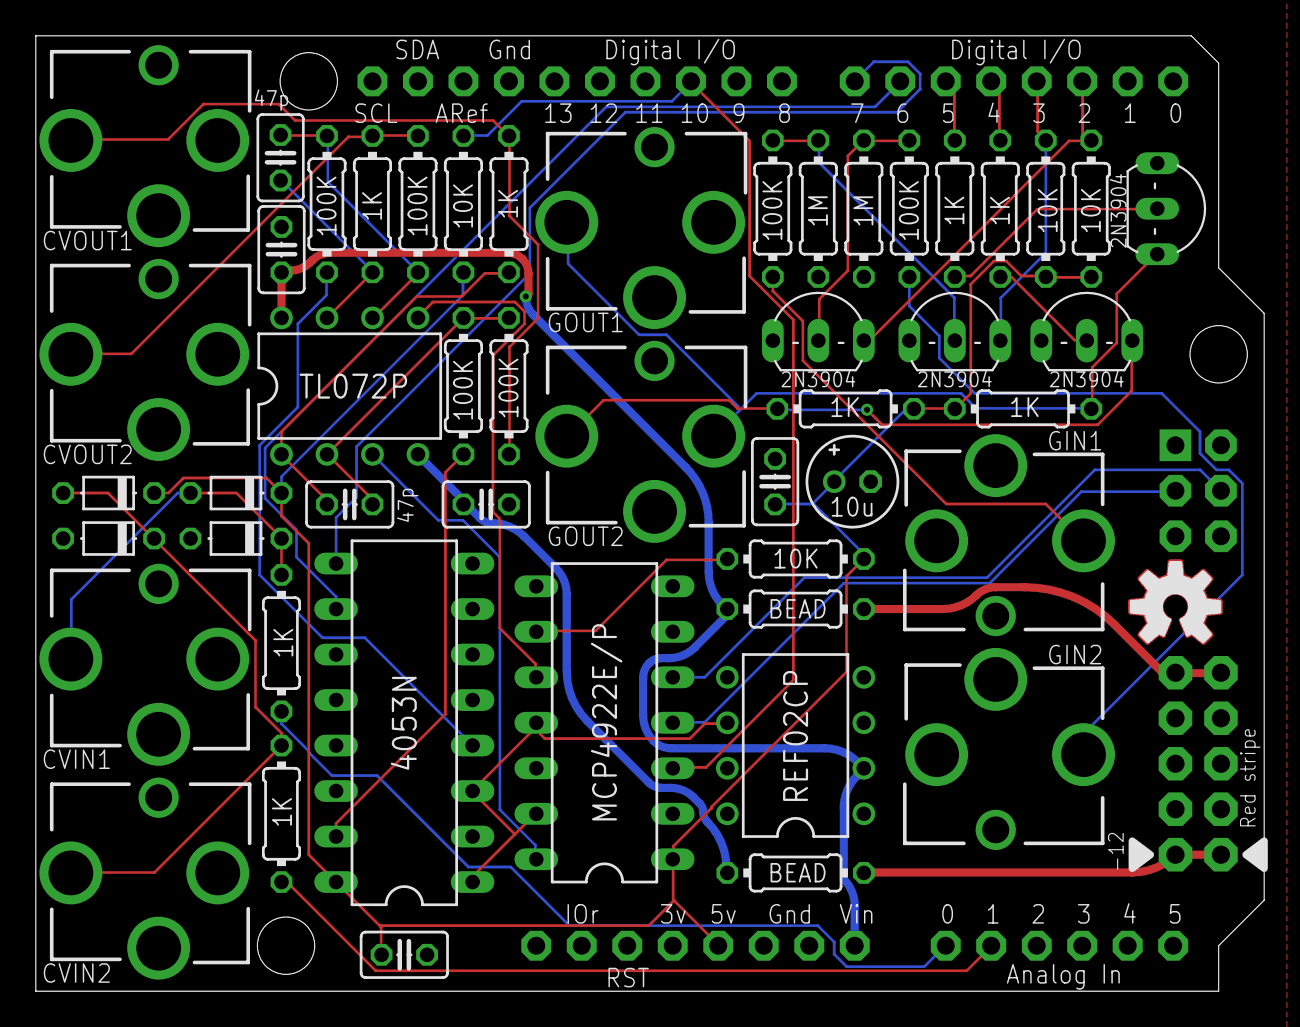
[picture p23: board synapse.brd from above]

Board: 2 copper layers, 68.6 x 53.3 mm, 53 parts (1 on the bottom side), 39 nets.

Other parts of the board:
U$1: OSHWLOGO_TOP_0.2
U$3: OSHW-LOGO-M

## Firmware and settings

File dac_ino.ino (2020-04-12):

/*
 Created: Rich Holmes, 2020
 Purpose: Control DAC, analog inputs, digital outputs
 Much of this borrowed from Chip Audette's ribbon controller code.
 */

#include <NewPing.h>
#include <SPI.h>

//debugging info
#define USE_ARDUINO  1
//#define USE_TEENSY  1
//#define Serial_t (Serial1)  //for MIDI for Arduino Micro or for TEENSY
#define Serial_t (Serial) //for MIDI for Arduino UNO or Pro Mini

// define the various pins used on the Arduino/Teensy hardware
const int d_in_a_pin = 2;
const int d_in_b_pin = 3;
const int d_in_c_pin = 4;
const int d_in_d_pin = 5;
const int d_out_a_pin = 6;
const int d_out_b_pin = 7;
const int a_in_a_pin = A0;
const int a_in_b_pin = A1;
const int a_in_c_pin = A2;
const int a_in_d_pin = A3;
const int a_in_e_pin = A4;
const int a_in_f_pin = A5;
const int slaveSelectPin = 10;  //for commanding the DAC

//sampling
volatile boolean flag_update_system = true;
volatile boolean flag_cannot_keep_up = false;
#define SAMPLE_RATE_HZ (600.0)

// Distance sensor setup
// d_in_a_pin is gate in
// d_out_a_pin is gate out

//Define HC-SR04 parameters
#define MAX_DISTANCE 350 // Maximum distance we want to ping for (in centimeters). Maximum sensor distance is rated at 400-500cm.
const int trigPin = d_out_b_pin;
const int echoPin = d_in_b_pin;
//setup SC-SR04 pins and max distance
NewPing sonar(trigPin, echoPin, MAX_DISTANCE); // NewPing setup of pins and maximum distance.

// Define window pot parameters
float R_pullup_A3_kOhm = 0.0;
float R_min_min_kOhm = 0.0;
float R_range_min_kOhm = 0.0;
const float R_min_max_kOhm = 17.45;
const float R_range_max_kOhm = 17.45;

// DAC parameters
#define MAX_DAC_COUNTS (4095)
#define VOLT_PER_OCTAVE (1.0)
#define MAX_DAC_VOLT (4.97)   //laptop is 5.04V, USB wall-wart is 5.182V
const float DAC_counts_per_volt = MAX_DAC_COUNTS/MAX_DAC_VOLT;


#ifdef USE_TEENSY
IntervalTimer sampleTimer; 
#endif

//Define some CV parameters
#define CV_note_bottom (0)  // no offset

volatile boolean startme = false;

//interrupt service routine...format of function call changes depending upon platform
#ifdef USE_TEENSY
void serviceTimer(void)     //Teensy convention
#else
  ISR(TIMER1_COMPA_vect)  //arduino convention
#endif
{
//  if (startme)
//  {
//    if (flag_update_system)
//      {
//        flag_cannot_keep_up = true;
//      }
  
    //read_HCSR04();
//  }
}

//setup routine
void setup() {
  // initialize the serial communications:
  //  Serial.begin(115200*2);  //for Arduino Micro only
  Serial.begin(9600);  // for Arduino Uno / Pro Mini
  delay(500);
  Serial.println("setup");

  //setup the HC-SR04 pins and the analogRead reference
  //analogReference(INTERNAL);
  //analogReference(EXTERNAL);
  pinMode(a_in_a_pin, INPUT_PULLUP);
  pinMode(a_in_b_pin, INPUT_PULLUP);
  
  //initialize the DAC
  pinMode(slaveSelectPin, OUTPUT);
  digitalWrite(slaveSelectPin,HIGH);  //set DAC ready to accept commands
  SPI.begin(); 
  SPI.setDataMode(SPI_MODE0); //MCP4922 can be either Mode 0 or Mode 3 (supposedly)
  SPI.setBitOrder(MSBFIRST);
  
  // setup window pots
  //  R_pullup_A3_kOhm = R_ribbon_max_kOhm * ( ((float)HCSR04_SPAN) / ((float)HCSR04_max_val) - 1.0 );
  //  R_min_min_kOhm = ((float)HCSR04_min_val) / ((float)HCSR04_max_val) * R_HCSR04_max_kOhm;
  //  R_max_min_kOhm = ((float)HCSR04_min_val) / ((float)HCSR04_max_val) * R_HCSR04_max_kOhm;
  
  //setup the timer
  float dt_sec_sample = 1.0 / SAMPLE_RATE_HZ;//arduino can run up to 1200Hz as of Mar 5, 2016
  
#ifdef USE_TEENSY
  int timer_loop_usec = (int)(dt_sec_sample*1000000.0); //microseconds
  sampleTimer.begin(serviceTimer, timer_loop_usec);
#else
  int timer_clock_divider = 64;  //see which divider I'm using in setupTimer()
  int timer_value = (int)( (16000000L) / ((long)timer_clock_divider) / ((long)SAMPLE_RATE_HZ) );
  setupTimer(timer_value);
#endif
  startme = true;
  Serial.println("setup done");
}



void loop()
{
//  Serial.println("loop");
  static int idle_counter = 0;
  
  if (flag_update_system)
    {
      flag_update_system = false;
      updateTheSystem();
    }
  else
    {
      idle_counter++;  //kill time without being stuck in an empty loop
    }
}

float HCSR04_duration = 0;
float HCSR04_distance = 0;
float CV_volts_offset = 0;
float CV_volts_per_cm = (5.0 - CV_volts_offset) / MAX_DISTANCE;
float CV_volts = 0;

bool gate;

void updateTheSystem() {
  
  // read input
  read_HCSR04(); //this is now done in the interrupt service routine!
  gate = digitalRead (d_in_b_pin);
  
  // process input
  process_HCSR04();
  
  // send CV to the DAC
  updateCV (CV_volts);

  // send gate to digital out
  digitalWrite (d_out_b_pin, gate);
}

void read_HCSR04(void) {
  Serial.println("read_HCSR04");
  
  //read the HCSR04 value
  if (true){
  HCSR04_duration = sonar.ping();
  }
  HCSR04_distance = (HCSR04_duration/2) * 0.0343;
  
  // maybe do some processing here
  
  //print some debugging info
  if (true) {
    if (flag_cannot_keep_up) {
      Serial.print(-HCSR04_distance); //enable this to get value at top and bottom of HCSR04 to calibrate
    } else {
      Serial.print(HCSR04_distance); //enable this to get value at top and bottom of HCSR04 to calibrate
    }
    Serial.print(" cm, duration ");
    Serial.print((int)HCSR04_duration); //enable this to get value at top and bottom of HCSR04 to calibrate
    Serial.println();
    flag_cannot_keep_up = false;
  }
  flag_update_system = true;
}

void process_HCSR04(void) {
  
  // For now we're ignoring the distance window pots
  
  CV_volts = CV_volts_offset + CV_volts_per_cm * HCSR04_distance;
  
  if (true)
    {
      Serial.print("CV_volts = ");
      Serial.println(CV_volts);
    }
}


#ifdef USE_ARDUINO
////Code from: http://letsmakerobots.com/node/28278
void setupTimer(const int &match_value_counts) {
  noInterrupts();           // disable all interrupts
  //we're going to use timer1
  TCCR1A = 0;  //enable normal operation (mode 0)
  TCCR1B = 0;
  TCNT1  = 0; //reset the counter
  
  // compare match register
  //  OCR1A = 0x7a12;           // compare match register...16MHz/prescaler/sample_rate_hz
  OCR1A = match_value_counts;
  TCCR1B |= (1 << WGM12);   // CTC mode
  //TCCR1B |= (1 << CS10);    // prescaler  (CS10=1)
  //TCCR1B |= (1 << CS11);    // prescaler  (CS11=8)
  TCCR1B |= ((1 << CS11) | (1 << CS10));  //CS11+CS10 = 64
  //TCCR1B |= ((1 << CS12) | (1 << CS10));  //CS12+CS10 = 1024
  TIMSK1 |= (1 << OCIE1A);  // enable timer compare interrupt
  interrupts();             // enable all interrupts
}
#endif 

void updateCV(const float &cv_volts)
{
  int cv_counts = (int)(cv_volts * DAC_counts_per_volt);
  cv_counts = constrain (cv_counts, 0, MAX_DAC_COUNTS);
  MCP4922_write (slaveSelectPin, cv_counts);
}

void MCP4922_write(const int &slavePin,const int &value) {
  byte configByte = 0;
  byte data=0;
  int channel=0;
  
  Serial.print ("MCP4922_write ");
  Serial.println (value);
  digitalWrite(slavePin,LOW);  //set DAC ready to accept commands
  configByte = B01110000; //channel 0, Vref buffered, Gain of 1x, Active Mode
  
  //write first byte
  data = highByte(value);
  data = B00001111 & data;  //clear out the 4 command bits
  data = configByte | data;  //set the first four command bits
  SPI.transfer(data);
  
  //write second byte
  data = lowByte(value);
  SPI.transfer(data);
  
  //close the transfer
  digitalWrite(slavePin,HIGH);  //set DAC ready to accept commands
  Serial.println ("done");
  
}

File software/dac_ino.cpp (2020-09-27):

/*
dac/ino
by Rich Holmes
based on Synapse:
=====
        ##########    Copyright (C) 2016 Vincenzo Pacella
        ##      ##    Distributed under MIT license, see file LICENSE-SW
        ##      ##    or <http://opensource.org/licenses/MIT>
        ##      ##
##########      ############################################################# shaduzlabs.com #####
=====
Changes mainly to do with increased number of inputs and outputs
and removal of code to control offset
*/


#include <Arduino.h>
#include "dac_ino.h"

//--------------------------------------------------------------------------------------------------

namespace
{
  static constexpr uint8_t k_writeChannelA = 0b01110000;
  static constexpr uint8_t k_writeChannelB = 0b11110000;
  
  static constexpr uint8_t k_pinCVInA = A0;
  static constexpr uint8_t k_pinCVInB = A1;
  static constexpr uint8_t k_pinCVInC = A2;
  static constexpr uint8_t k_pinCVInD = A3;
  static constexpr uint8_t k_pinCVInE = A4;
  static constexpr uint8_t k_pinCVInF = A5;
  static constexpr uint8_t k_pinCVInG = A6;
  static constexpr uint8_t k_pinCVInH = A7;
}

//--------------------------------------------------------------------------------------------------

namespace dcrd
{

//--------------------------------------------------------------------------------------------------

dac_ino dac_inoBoard;

//--------------------------------------------------------------------------------------------------

void dac_ino::begin(unsigned spiDivider_)
{
  pinMode(k_pinCVInA, INPUT);
  pinMode(k_pinCVInB, INPUT);
  pinMode(k_pinGateInA, INPUT);
  pinMode(k_pinGateInB, INPUT);
  pinMode(k_pinGateInC, INPUT);
  pinMode(k_pinGateInD, INPUT);
  pinMode(k_pinGateInE, INPUT);
  pinMode(k_pinGateInF, INPUT);
  
  pinMode(k_pinChipSelectDAC, OUTPUT);
  pinMode(k_pinGateOutA, OUTPUT);
  pinMode(k_pinGateOutB, OUTPUT);

  m_gateInEEnabled = true;
  m_gateInFEnabled = true;
  m_gateOutCEnabled = false;
  m_gateOutDEnabled = false;
  
#if defined __AVR__
  m_outputChipSelectDAC = HIGH;
#else
  digitalWrite(k_pinChipSelectDAC, HIGH);
#endif

  SPI.begin();

  SPI.setBitOrder(MSBFIRST);
  SPI.setDataMode(SPI_MODE0);
  setSPIDivider(spiDivider_);
}

//--------------------------------------------------------------------------------------------------

void dac_ino::setGateToOutput (GateOutChannel channel_)
{
  switch (channel_)
    {
    case GateOutChannel::C:
      pinMode(k_pinGateOutC, OUTPUT);
      m_gateOutCEnabled = true;
      m_gateInEEnabled = false;
      break;
    case GateOutChannel::D:
      pinMode(k_pinGateOutD, OUTPUT);
      m_gateOutDEnabled = true;
      m_gateInFEnabled = false;
      break;
    default:
      return;
    }
}
  
//--------------------------------------------------------------------------------------------------

void dac_ino::setGateToInput (GateInChannel channel_)
{
  switch (channel_)
    {
    case GateInChannel::E:
      pinMode(k_pinGateInE, INPUT);
      m_gateInEEnabled = true;
      m_gateOutCEnabled = false;
      break;
    case GateInChannel::F:
      pinMode(k_pinGateInF, OUTPUT);
      m_gateInFEnabled = true;
      m_gateOutDEnabled = false;
      break;
    default:
      return;
    }
}
  
//--------------------------------------------------------------------------------------------------

unsigned dac_ino::readCV(CVInChannel channel_)
{
  switch (channel_)
  {
    case CVInChannel::A:
      return analogRead(k_pinCVInA);
    case CVInChannel::B:
      return analogRead(k_pinCVInB);
    case CVInChannel::C:
      return analogRead(k_pinCVInC);
    case CVInChannel::D:
      return analogRead(k_pinCVInD);
    case CVInChannel::E:
      return analogRead(k_pinCVInE);
    case CVInChannel::F:
      return analogRead(k_pinCVInF);
    case CVInChannel::G:
      return analogRead(k_pinCVInG);
    case CVInChannel::H:
      return analogRead(k_pinCVInH);
    default:
      return 0U;
  }
}

//--------------------------------------------------------------------------------------------------

void dac_ino::writeCV(CVOutChannel channel_, uint16_t value_)
{
  uint8_t msg1 = (uint8_t)((value_ >> 8) & 0x0F);
  uint8_t msg2 = (uint8_t)(value_ & 0xFF);

  switch (channel_)
  {
    case CVOutChannel::A:
    {
      msg1 |= k_writeChannelA;
      break;
    }
    case CVOutChannel::B:
    {
      msg1 |= k_writeChannelB;
      break;
    }
    default:
    {
      return;
    }
  }

#if defined __AVR__
  m_outputChipSelectDAC = LOW;
#else
  digitalWrite(k_pinChipSelectDAC, LOW);
#endif

  SPI.transfer(msg1);
  SPI.transfer(msg2);

#if defined __AVR__
  m_outputChipSelectDAC = HIGH;
#else
  digitalWrite(k_pinChipSelectDAC, HIGH);
#endif
}

//--------------------------------------------------------------------------------------------------

bool dac_ino::readGate(GateInChannel channel_)
{
  // Channels A through D have inverting input circuitry!
  // Channels E and F do not.
  
  switch (channel_)
  {
    case GateInChannel::A:
    {
#if defined __AVR__
      return !(m_inputGateA);
#else
      return !(digitalRead(k_pinGateInA));
#endif
    }
    case GateInChannel::B:
    {
#if defined __AVR__
      return !(m_inputGateB);
#else
      return !(digitalRead(k_pinGateInB));
#endif
    }
    case GateInChannel::C:
    {
#if defined __AVR__
      return !(m_inputGateC);
#else
      return !(digitalRead(k_pinGateInC));
#endif
    }
    case GateInChannel::D:
    {
#if defined __AVR__
      return !(m_inputGateD);
#else
      return !(digitalRead(k_pinGateInD));
#endif
    }
    case GateInChannel::E:
    {
      if (!m_gateInEEnabled)
	return false;
#if defined __AVR__
      return m_inputGateE;
#else
      return digitalRead(k_pinGateInE);
#endif
    }
    case GateInChannel::F:
    {
      if (!m_gateInFEnabled)
	return false;
#if defined __AVR__
      return m_inputGateF;
#else
      return digitalRead(k_pinGateInF);
#endif
    }
    default:
    {
      return false;
    }
  }
}

//--------------------------------------------------------------------------------------------------

void dac_ino::writeGate(GateOutChannel channel_, bool state_)
{
  switch (channel_)
  {
    case GateOutChannel::A:
    {
#if defined __AVR__
      m_outputGateA = state_ ? LOW : HIGH;
#else
      digitalWrite(k_pinGateOutA, (state_ ? LOW : HIGH));
#endif

      break;
    }
    case GateOutChannel::B:
    {
#if defined __AVR__
      m_outputGateB = state_ ? LOW : HIGH;
#else
      digitalWrite(k_pinGateOutB, (state_ ? LOW : HIGH));
#endif
      break;
    }
    case GateOutChannel::C:
    {
      if (!m_gateOutCEnabled)
	break;
#if defined __AVR__
      m_outputGateC = state_ ? LOW : HIGH;
#else
      digitalWrite(k_pinGateOutC, (state_ ? LOW : HIGH));
#endif

      break;
    }
    case GateOutChannel::D:
    {
      if (!m_gateOutDEnabled)
	break;
#if defined __AVR__
      m_outputGateD = state_ ? LOW : HIGH;
#else
      digitalWrite(k_pinGateOutD, (state_ ? LOW : HIGH));
#endif
      break;
    }
    default:
    {
      return;
    }
  }
}
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

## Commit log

2016-03-15 Updated schematic
2016-03-15 travis.yml: updated Arduino version to 1.6.8
2016-09-20 added hardware project files, updated readme
    [synapse.brd, synapse.sch]
2016-11-24 update list of compatible boards
2016-11-24 extend compatibility to non-AVR boards
2018-06-27 Use of angled 5x2 male strips
    Noticed you could use angled 5x2 strips for the IDC connector, so it would be possible to stack another header on top.
2018-07-09 Fix reset state check
    [ClockDivide.ino]
2018-07-09 Fix pot value scaling
    [ClockDivide.ino]
2018-07-09 Fix analog in pin numbers
2020-03-25 Original synapse hardware to orig_hardware; new KiCad files in hardware/dacarduino and hardware/dacarduino\ lite
    [Arduino.sch, CV_in.sch, CVout.sch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]
2020-03-27 Revised layout, with voltage reference restored to dacarduino
    [Arduino.sch, CV_in.sch, CVout.sch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]
2020-03-27 KiCad version of original hardware design
    [synapse.kicad_pcb, synapse.sch, synapse_1.sch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]
2020-04-07 Revise switches plan
2020-04-07 PCB redraw; change op amp selection; revise power tags; move to spaceless directory
    [Arduino.sch, CV_in.sch, CVout.sch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]
2020-04-12 Backlog of many changes
    [Arduino.sch, CV_in.sch, CVout.sch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]
2020-04-12 Redid layout completely
    [dacarduino.kicad_pcb]
2020-04-12 Additional inputs since the board has room
    [Arduino.sch, CV_in.sch, CVout.sch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]
2020-04-13 Added hack area
    [dacarduino.kicad_pcb]
2020-04-24 Add multiplexer option
    [Arduino.sch, CV_in.sch, Gate_out.sch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]
2020-04-24 Revert multiplexer idea
    [Arduino.sch, CV_in.sch, Gate_out.sch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]
2020-05-03 Post-prototype tweaks
    [Arduino.sch, DAC.sch, Gate_out.sch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]
2020-05-04 Name change
    [Arduino.sch, CV_in.sch, CVout.sch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]
2020-05-04 dac_ino Gerbers added
    [dac_ino-B_Cu.gbr, dac_ino-B_Mask.gbr, dac_ino-B_Paste.gbr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]
2020-05-04 Redo Gerbers
    [dac_ino-B_Cu.gbr, dac_ino-B_Mask.gbr, dac_ino-B_Paste.gbr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]
2020-05-04 Consistent annotation; BOMs
    [Arduino.sch, CV_in.sch, CVout.sch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]
2020-05-04 Late silkscreen work
    [dac_ino-B_Cu.gbr, dac_ino-B_Mask.gbr, dac_ino-B_Paste.gbr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]
2020-05-09 Remove experimental artwork...
    [dac_ino-B_Cu.gbr, dac_ino-B_Mask.gbr, dac_ino-B_Paste.gbr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]
2020-05-15 Tweak fab layers and jack descriptions
    [Arduino.sch, CV_in.sch, CVout.sch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]
2020-05-16 Correct output op amp connections
    [CVout.sch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]
2020-05-17 Add headers for board coupling
    [Arduino.sch, CV_in.sch, CVout.sch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]
2020-05-18 Final tweaks before fabbing revised board
    [dac_ino-B_Cu.gbr, dac_ino-B_Mask.gbr, dac_ino-B_Paste.gbr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]
2020-05-28 Corrected output range for quantizer
    [SimpleQuant.ino]
2020-06-05 Rearrange PCB to make headers easier to use
    [CV_in.sch, Gate_in.sch, dac_ino.kicad_pcb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]
2020-06-06 Reorient header
    [Arduino.sch, CV_in.sch, Gate_in.sch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]
2020-06-06 Daughterboard template project
    [daughterboard.kicad_pcb, daughterboard.sch]
2020-06-07 Daughterboard edge adjustments, pdf and png
    [daughterboard.kicad_pcb]
2020-06-07 Pin labels
    [daughterboard.kicad_pcb, daughterboard.sch]
2020-07-04 Rearrange 8 pin Molex; convert footprints to AO versions and clean up silkscreen
    [Arduino.sch, CV_in.sch, CVout.sch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]
2020-07-04 New Gerbers
    [dac_ino-B_Cu.gbr, dac_ino-B_Mask.gbr, dac_ino-B_Paste.gbr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]
2020-07-30 Newer Gerbers; correct silkscreen; note on silkscreen error
    [dac_ino-B_Cu.gbr, dac_ino-B_Mask.gbr, dac_ino-B_Paste.gbr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]
2020-08-24 Layer visibility
    [dac_ino.kicad_pcb]
2020-08-26 Nano interrupts are only pin 2, 3
2020-08-28 Fix silkscreen error
    [dac_ino-B_Cu.gbr, dac_ino-B_Mask.gbr, dac_ino-B_Paste.gbr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]
2020-08-30 Docs directory with dac/ino schematics and layout
2020-08-30 BOM to docs directory
2020-08-30 BOM link in README
2020-09-08 Fix hopelessly out of date BOM
2020-09-27 Fix up some typos (that never should have made it to the repository!)
    [dac_ino.cpp, dac_ino.h]
2020-11-28 Documentation updates, TODO
    [CVout.sch]
2021-01-02 Footprints updated
2021-01-24 Fix J1, J2 3D
    [dac_ino.kicad_pcb]
2021-02-02 Ungarble labels
    [dac_ino.kicad_pcb]
2021-02-19 Footprint update
2021-02-27 Fix C2 labeling
    [dac_ino.kicad_pcb]
2021-03-13 Clarify silkscreen correction
2021-05-10 Less insane redraw of dac/ino lite schems
    [Arduino.sch, CV_in.sch, CVout.sch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]

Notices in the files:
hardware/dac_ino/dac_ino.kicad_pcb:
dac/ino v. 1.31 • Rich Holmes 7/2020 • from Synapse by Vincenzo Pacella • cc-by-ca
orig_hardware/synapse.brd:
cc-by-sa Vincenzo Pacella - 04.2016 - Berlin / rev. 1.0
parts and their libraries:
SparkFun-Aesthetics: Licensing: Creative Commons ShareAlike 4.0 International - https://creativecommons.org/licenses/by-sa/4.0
